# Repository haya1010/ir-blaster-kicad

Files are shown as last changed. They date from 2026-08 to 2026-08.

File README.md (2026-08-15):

# M5 / ESP32 High-Power IR Blaster — Rev A

M5 Atom または ESP32 から家電を操作するための、赤外線送受信ボードです。
既存の `m5-ir-remote-studio` の初期設定に合わせ、送信は GPIO26、受信は GPIO32 を想定しています。

## できること

- 940 nm 高出力IR LEDを3灯同時にパルス駆動
- AO3400A MOSFETでESP32のGPIOを保護
- TSOP38238（38 kHz）でリモコン信号を受信
- 受信部を3.3 Vで動かし、ESP32入力へ安全な電圧で返す
- TX動作確認用の可視LED
- JST-PH 4ピンでM5 Atom／ESP32へ接続
- 52 × 40 mm、M3穴4個

## 接続

| J1 pin | 信号 | M5 Atom / ESP32 |
|---|---|---|
| 1 | IR_TX | GPIO26 |
| 2 | IR_RX | GPIO32 |
| 3 | +5V | 5V |
| 4 | GND | GND |

J1のシルク面表記は左から `TX / RX / 5V / GND` です。Groveケーブルは製品により信号線の割り当てが異なるため、色だけで判断せず導通を確認してください。

## 電気的な目安

IR LED 1灯あたりのピーク電流は、5 V、順方向電圧約1.35 V、33 Ωとして約111 mAです。
3灯合計は送信パルス中に約333 mAとなります。38 kHz変調かつ短いリモコン送信を前提としています。

連続点灯はしないでください。IR LEDにはパルス定格に余裕のある部品（TSAL6200相当）を使い、R3〜R5はパルス負荷に耐える0.5 W品を推奨します。

## KiCadで開く

`m5_ir_blaster.kicad_pro` または `m5_ir_blaster.kicad_pcb` を開いてください。
フットプリントはPCBファイル内に埋め込んであるため、追加ライブラリは不要です。

## JLCPCBで基板だけ注文する

アップロードするファイルは `manufacturing/m5_ir_blaster_revA_gerbers.zip` です。
KiCadプロジェクトZIPではなく、Gerber ZIPの方を使ってください。

推奨する初回設定:

| 項目 | 設定 |
|---|---|
| Base Material | FR-4 |
| Layers | 2 |
| Dimensions | 52 × 40 mm（自動認識を確認） |
| PCB Qty | 5 |
| Thickness | 1.6 mm |
| Copper Weight | 1 oz |
| PCB Color | Green（好みで変更可） |
| Silkscreen | White |
| Surface Finish | LeadFree HASL |
| Via Covering | Tented |
| Remove Order Number | 見た目優先なら Yes |
| PCB Assembly | No（部品は手はんだ） |

アップロード後のGerber Viewerで、外形、M3穴4個、IR LED穴3組、J1の4ピン穴、表面シルクを確認してください。

## 製造前の確認

これは試作Rev Aです。発注前に次を確認してください。

1. 使用するJSTコネクタの実物とピン順
2. 選んだIR LEDの極性と最大パルス電流
3. TSOP38238互換品のピン配列（OUT / GND / VS）
4. KiCadのDRC
5. 実機の5 V供給能力

## データシート確認済みの要点

- MCP1700 SOT-23: 1=GND、2=VOUT、3=VIN
- TSOP38238: 1=OUT、2=GND、3=VS
- TSAL6200: 940 nm、連続100 mA、規定条件でピーク200 mA
- AO3400A: 2.5 Vゲート駆動時のオン抵抗が規定されたロジックレベルMOSFET

メーカー資料:

- https://www.microchip.com/en-us/product/mcp1700
- https://www.vishay.com/docs/82491/tsop382.pdf
- https://www.vishay.com/docs/81010/tsal6200.pdf
- https://www.aosmd.com/products/mosfets/low-voltage-mosfets-12v-30v/ao3400a

## ファームウェア

既存スケッチの設定をそのまま使用できます。

```cpp
static const uint16_t IR_RX_PIN = 32;
static const uint16_t IR_TX_PIN = 26;
```

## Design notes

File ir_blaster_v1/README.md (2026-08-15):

# IR Blaster V1 — ESP32 DevKitC 38-pin shield

写真のユニバーサル基板版を、74.0 mm円形・2層PCBとして再構成したKiCad 9プロジェクトです。12灯のLEDとESP32用1×19ピンソケット2本は、ユーザーの指定により **DNP（未実装）** とし、スルーホール、極性表示、外向き矢印だけを用意しています。

## 確定仕様

- `BOARD_DIAMETER_MM = 74.0`
- 2-layer FR-4、1.6 mm、1 oz
- 推奨色: White solder mask / Black silkscreen
- ESP32 DevKitC V4: 2.54 mmピッチ×19、2列間隔25.40 mm、基板幅27.94 mm
- IR LED: 12個。広角4個（0/90/180/270°）、狭角8個（その間の30°刻み）
- LED/ESP32ソケット: DNP、ユーザー手はんだ
- GPIO25 → 220 Ω → INK021ABS1 gate、10 kΩ pull-down
- 5 V–GND: 1000 µF + 100 nF

## ファイル

- `ir_blaster_v1.kicad_pro/.kicad_sch/.kicad_pcb`: KiCadプロジェクト
- `manufacturing/`: Gerber、Excellon、製造ZIP
- `assembly/`: BOM/CPL候補（LEDとソケットは除外）
- `docs/`: 回路図、基板PDF、組立図
- `preview/`: Top/Bottom/3D PNG
- `BOM.csv`, `BOM_REVIEW.md`, `DESIGN_REVIEW.md`, `JLCPCB_ORDER_GUIDE.md`, `ASSUMPTIONS.md`

## 検証結果

- KiCad ERC: 0 error / 0 warning
- KiCad PCB DRC: 0 DRC violations
- KiCad 9.0.6では、塗り潰し済み+5Vゾーンが自分自身の同一点を指す `1 unconnected pads` 診断を出します。部品パッド間の未配線ではなく、Gerberと銅箔PDFでゾーン連続性を確認しています。

## 発注前に必ず確認

1. 手元のESP32ボードが公式DevKitC V4互換の25.40 mm列間隔・19ピンであること。
2. 使用するメスソケットのピンが1.0 mm完成穴を通ること。
3. LEDは1番穴=A、2番穴=K。全12個を外向き30〜45°程度に手はんだすること。
4. Q1の3.3 V動作はメーカー保証値ではないため、最初は電流制限付き電源で確認すること。
5. JLCPCB注文画面でQ1およびTHT受動部品の実在庫・フットプリントを再確認すること。

## 公式資料

- Espressif DevKitC V4: https://docs.espressif.com/projects/esp-dev-kits/en/latest/esp32/esp32-devkitc/user_guide.html
- DevKitC寸法PDF: https://dl.espressif.com/dl/schematics/esp32_devkitc_v4_dimensions.pdf
- OSI5LA5A33A-B datasheet: https://akizukidenshi.com/goodsaffix/OSI5LA5A33A-B.pdf
- OSI5LA7WA1B datasheet: https://akizukidenshi.com/goodsaffix/OSI5LA7WA1B.pdf
- INK021ABS1 datasheet: https://www.idc-com.co.jp/product/Search/Pdf/en/121/INK021ABS1/0/

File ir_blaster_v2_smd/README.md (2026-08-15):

# IR Blaster V2 SMD

Cost-optimized derivative of `ir_blaster_v1`.

- User hand solder: D1-D12 IR LEDs, J1/J2 ESP32 DevKit sockets, Cbulk 1000 uF
- JLCPCB top-side SMT: R1-R12, RG, RPD, Q1, Cdec
- R1-R12 use 1206 250 mW parts for LED-current resistor power margin
- Q1 changes from the THT INK021ABS1 to the 3.3 V logic-level AO3400A (SOT-23)
- Electrical control remains GPIO25 through 220 ohm gate resistance with 10 kohm pull-down

Manufacturing uploads:

- `manufacturing/ir_blaster_v2_smd_gerbers_jlc.zip`
- `assembly/BOM_JLCPCB.csv`
- `assembly/CPL_JLCPCB.csv`

Do not place an order until the final KiCad zone-fill/connectivity and JLCPCB placement preview have been reviewed.

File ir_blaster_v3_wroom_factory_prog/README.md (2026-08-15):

# IR Blaster V3 — WROOM Factory Programming Interface

This is a separate KiCad revision. It does not overwrite `ir_blaster_v1` or
`ir_blaster_v2_smd`.

## Scope

This revision implements the section-8 programming interface milestone:

- ESP32-WROOM-32E-N16 footprint and UART0 programming nets
- bottom-side six-pad factory pogo interface
- separate 2.54 mm 1x6 prototype header, marked DNP
- pin-1 and per-signal silkscreen labels
- JLCPCB BOM/CPL and fabrication outputs
- safe programming instructions

It is an integration milestone, not yet the complete standalone product. USB-C,
the regulator, IR LED drivers, IR receiver, bulk capacitor, buttons and final
case/3D interference checks still need to be merged from the master specification
before a production order.

## Pinout

| Pin | Net | Board label |
|---:|---|---|
| 1 | +3V3 | 3V3 |
| 2 | GND | GND |
| 3 | ESP32 TXD0 | TX |
| 4 | ESP32 RXD0 | RX |
| 5 | EN | EN |
| 6 | IO0 | IO0 |

The bottom pogo pads use the same order in a straight 1x6 array at 3.81 mm
pitch. Pad diameter is 2.4 mm and pad 1 is rectangular.

## Verification status

- PCB DRC: 0 electrical errors, 0 unconnected pads
- Schematic ERC: 0 violations
- Remaining DRC warnings: embedded custom pogo footprint library entries and
  the intentional WROOM footprint change described below

The official KiCad `ESP32-WROOM-32E` land pattern is used. Its 0.20 mm exposed-
pad thermal-via drills were enlarged to 0.30 mm with 0.70 mm pads to fit the
normal JLCPCB manufacturing capability/cost class. This intentional difference
is why KiCad reports a library mismatch warning for U1.

## Manufacturing files

- `manufacturing/gerbers/`: Gerber and drill files
- `manufacturing/ir_blaster_v3_wroom_factory_prog_gerbers.zip`: PCB upload ZIP
- `assembly/BOM_JLCPCB.csv`: assembled parts only
- `assembly/CPL_JLCPCB.csv`: placement data
- `BOM.csv`: engineering BOM including DNP items

`J_PROG` and all pogo pads are PCB-only/DNP and are excluded from the JLCPCB
production BOM and placement file.

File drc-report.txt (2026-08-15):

** Drc report for m5_ir_blaster.kicad_pcb **
** Created on 2026-07-31T15:13:33+0900 **

** Found 0 DRC violations **

** Found 0 unconnected pads **

** Found 0 Footprint errors **

** End of Report **

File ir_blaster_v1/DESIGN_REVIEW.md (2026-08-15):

# Design review

## 電気計算

前提を `VLED = 1.6 V`、`R = 100 Ω`、`VDS = 0.2 V` とすると、1灯のパルス電流は `(5 - 1.6 - 0.2) / 100 = 32 mA`、12灯合計は約384 mAです。抵抗損失は1本あたり約0.102 Wで、指定の0.25 W品に対して余裕があります。

INK021ABS1はメーカー資料で1=Source、2=Drain、3=Gateです。`RDS(on)` は `VGS=4.5 V, ID=1 A` でtyp 0.2 Ω / max 0.35 Ωですが、3.3 Vでの最大値は保証されません。グラフから0.4 A級のスイッチングは現実的と判断できますが、量産保証には不足します。0.35 Ωを仮定した12灯ON時損失は約52 mW、0.6 Ωでも約88 mWです。V1は動作済み試作との同等性を優先して部品を維持しました。

代替候補を使う場合は、3.3 V以下で`RDS(on)`最大値が規定されたlogic-level MOSFETを選び、ピン配列とフットプリントを別リビジョンで再検証してください。V1の製造ファイルでは勝手に置換していません。

Gateは220 Ωと入力容量typ 660 pFから、単純化した時定数が約145 nsです。38 kHz周期26.3 µsに対して十分短く、GPIOの定常電流はほぼ0です。

1000 µFは短いmarkで5 Vバスの落ち込みを抑えます。384 mAを600 µs補う理想計算では約0.23 V低下します。長いmarkをコンデンサだけで支えるものではありません。

38 kHzでLED駆動デューティ1/3なら、mark中の平均LED電流は約128 mAです。プロトコルのspaceを含む送信全体平均はさらに低下します。ただしESP32のWi‑Fiピークと同時に最大約0.4 Aを追加するため、品質のよい5 V / 1 A以上のUSB電源を推奨します。Espressifの注意どおり、USB・5Vピン・3V3ピンから複数電源を同時供給しないでください。

## LED実装方針

JLCPCBは部品ライブラリ上でwave soldering指定されたTHT部品やmanual insertionを扱えます。一方、通常のTHT注文だけで「LED光軸を外向き30〜45°に揃える」ことを保証する公開標準は確認できません。今回はユーザー指定どおりOption C、すなわちLEDをDNPにして手はんだします。基板にはA/K、カソード帯、外向き矢印を入れています。

## ESP32メカ

公式寸法の25.40 mm列間隔、2.54 mmピッチ、19ピンを採用しました。USB側を基板下方向にし、アンテナ側を上方向に表示しています。円形基板と公式DevKitC外形は一部重なるため、アンテナ直下の中央上部に配線を密集させない配置としています。クローン基板は外形・USB・ボタン位置が異なることがあるため実物照合が必要です。

## Photo prototype vs New PCB

| 項目 | Photo prototype | New PCB V1 |
|---|---|---|
| LED数 | 12 | 12 |
| LED種類 | 青透明8、透明wide 4に見える | narrow 8 / wide 4 |
| LED位置 | 円周方向 | 30°刻みの12方向 |
| LED方向 | 外向きに傾斜 | 穴は垂直、手はんだ時に外向き30〜45° |
| コンデンサ | 中央付近 | 中央付近 |
| MOSFET | 中央付近 | 中央付近、S/D/G表示 |
| ESP32 | 下側に積層 | 25.40 mmソケット2列で下側に積層 |
| USB方向 | 円の外側方向 | `USB ↓` |
| 外径 | 写真から約70 mm級 | 74.0 mm |

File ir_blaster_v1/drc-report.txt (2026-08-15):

** Drc report for ir_blaster_v1.kicad_pcb **
** Created on 2026-08-11T19:46:53+0900 **

** Found 0 DRC violations **

** Found 1 unconnected pads **
[unconnected_items]: アイテム間の接続が見つからない
    ローカル オーバーライド; error
    @(100.0000 mm, 77.5000 mm): ゾーン [+5V] F.Cu 上, 優先度 0
    @(100.0000 mm, 77.5000 mm): ゾーン [+5V] F.Cu 上, 優先度 0

** Found 0 Footprint errors **

** End of Report **

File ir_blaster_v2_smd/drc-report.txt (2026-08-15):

** Drc report for ir_blaster_v2_smd.kicad_pcb **
** Created on 2026-08-11T20:14:26+0900 **

** Found 169 DRC violations **
[via_dangling]: ビアがレイヤーに未接続か、単一のレイヤーにのみ接続
    ローカル オーバーライド; warning
    @(99.0000 mm, 116.9500 mm): ビア [GND] (F.Cu - B.Cu 上)
[via_dangling]: ビアがレイヤーに未接続か、単一のレイヤーにのみ接続
    ローカル オーバーライド; warning
    @(108.0000 mm, 116.9500 mm): ビア [GND] (F.Cu - B.Cu 上)
[via_dangling]: ビアがレイヤーに未接続か、単一のレイヤーにのみ接続
    ローカル オーバーライド; warning
    @(102.9000 mm, 101.0000 mm): ビア [GND] (F.Cu - B.Cu 上)
[lib_footprint_issues]: 現在の構成にはフットプリント ライブラリ 'IR_Blaster' が含まれていません。
    ローカル オーバーライド; warning
    @(100.0000 mm, 67.8000 mm): フットプリント D1
[lib_footprint_mismatch]: フットプリント 'R_1206_3216Metric' が、ライブラリ 'Resistor_SMD' のコピーと一致しません。
    ローカル オーバーライド; warning
    @(100.0000 mm, 78.0000 mm): フットプリント R1
[lib_footprint_issues]: 現在の構成にはフットプリント ライブラリ 'IR_Blaster' が含まれていません。
    ローカル オーバーライド; warning
    @(116.1000 mm, 72.1140 mm): フットプリント D2
[lib_footprint_mismatch]: フットプリント 'R_1206_3216Metric' が、ライブラリ 'Resistor_SMD' のコピーと一致しません。
    ローカル オーバーライド; warning
    @(107.5000 mm, 87.0100 mm): フットプリント R2
[lib_footprint_issues]: 現在の構成にはフットプリント ライブラリ 'IR_Blaster' が含まれていません。
    ローカル オーバーライド; warning
    @(127.8860 mm, 83.9000 mm): フットプリント D3
[lib_footprint_mismatch]: フットプリント 'R_1206_3216Metric' が、ライブラリ 'Resistor_SMD' のコピーと一致しません。
    ローカル オーバーライド; warning
    @(119.0530 mm, 89.0000 mm): フットプリント R3
[lib_footprint_issues]: 現在の構成にはフットプリント ライブラリ 'IR_Blaster' が含まれていません。
    ローカル オーバーライド; warning
    @(132.2000 mm, 100.0000 mm): フットプリント D4
[lib_footprint_mismatch]: フットプリント 'R_1206_3216Metric' が、ライブラリ 'Resistor_SMD' のコピーと一致しません。
    ローカル オーバーライド; warning
    @(122.0000 mm, 100.0000 mm): フットプリント R4
[lib_footprint_issues]: 現在の構成にはフットプリント ライブラリ 'IR_Blaster' が含まれていません。
    ローカル オーバーライド; warning
    @(127.8860 mm, 116.1000 mm): フットプリント D5
[lib_footprint_mismatch]: フットプリント 'R_1206_3216Metric' が、ライブラリ 'Resistor_SMD' のコピーと一致しません。
    ローカル オーバーライド; warning
    @(119.0530 mm, 111.0000 mm): フットプリント R5
[lib_footprint_issues]: 現在の構成にはフットプリント ライブラリ 'IR_Blaster' が含まれていません。
    ローカル オーバーライド; warning
    @(116.1000 mm, 127.8860 mm): フットプリント D6
[lib_footprint_mismatch]: フットプリント 'R_1206_3216Metric' が、ライブラリ 'Resistor_SMD' のコピーと一致しません。
    ローカル オーバーライド; warning
    @(111.0000 mm, 119.0530 mm): フットプリント R6
[lib_footprint_issues]: 現在の構成にはフットプリント ライブラリ 'IR_Blaster' が含まれていません。
    ローカル オーバーライド; warning
    @(100.0000 mm, 132.2000 mm): フットプリント D7
[lib_footprint_mismatch]: フットプリント 'R_1206_3216Metric' が、ライブラリ 'Resistor_SMD' のコピーと一致しません。
    ローカル オーバーライド; warning
    @(100.0000 mm, 122.0000 mm): フットプリント R7
[lib_footprint_issues]: 現在の構成にはフットプリント ライブラリ 'IR_Blaster' が含まれていません。
    ローカル オーバーライド; warning
    @(83.9000 mm, 127.8860 mm): フットプリント D8
[lib_footprint_mismatch]: フットプリント 'R_1206_3216Metric' が、ライブラリ 'Resistor_SMD' のコピーと一致しません。
    ローカル オーバーライド; warning
    @(89.0000 mm, 119.0530 mm): フットプリント R8
[lib_footprint_issues]: 現在の構成にはフットプリント ライブラリ 'IR_Blaster' が含まれていません。
    ローカル オーバーライド; warning
    @(72.1140 mm, 116.1000 mm): フットプリント D9
[lib_footprint_mismatch]: フットプリント 'R_1206_3216Metric' が、ライブラリ 'Resistor_SMD' のコピーと一致しません。
    ローカル オーバーライド; warning
    @(80.9470 mm, 111.0000 mm): フットプリント R9
[lib_footprint_issues]: 現在の構成にはフットプリント ライブラリ 'IR_Blaster' が含まれていません。
    ローカル オーバーライド; warning
    @(67.8000 mm, 100.0000 mm): フットプリント D10
[lib_footprint_mismatch]: フットプリント 'R_1206_3216Metric' が、ライブラリ 'Resistor_SMD' のコピーと一致しません。
    ローカル オーバーライド; warning
    @(78.0000 mm, 100.0000 mm): フットプリント R10
[lib_footprint_issues]: 現在の構成にはフットプリント ライブラリ 'IR_Blaster' が含まれていません。
    ローカル オーバーライド; warning
    @(72.1140 mm, 83.9000 mm): フットプリント D11
[lib_footprint_mismatch]: フットプリント 'R_1206_3216Metric' が、ライブラリ 'Resistor_SMD' のコピーと一致しません。
    ローカル オーバーライド; warning
    @(80.9470 mm, 89.0000 mm): フットプリント R11
[lib_footprint_issues]: 現在の構成にはフットプリント ライブラリ 'IR_Blaster' が含まれていません。
    ローカル オーバーライド; warning
    @(83.9000 mm, 72.1140 mm): フットプリント D12
[lib_footprint_mismatch]: フットプリント 'R_1206_3216Metric' が、ライブラリ 'Resistor_SMD' のコピーと一致しません。
    ローカル オーバーライド; warning
    @(92.5000 mm, 87.0100 mm): フットプリント R12
[lib_footprint_issues]: 現在の構成にはフットプリント ライブラリ 'IR_Blaster' が含まれていません。
    ローカル オーバーライド; warning
    @(87.3000 mm, 72.0000 mm): フットプリント J1
[lib_footprint_issues]: 現在の構成にはフットプリント ライブラリ 'IR_Blaster' が含まれていません。
    ローカル オーバーライド; warning
    @(112.7000 mm, 72.0000 mm): フットプリント J2
[lib_footprint_mismatch]: フットプリント 'SOT-23' が、ライブラリ 'Package_TO_SOT_SMD' のコピーと一致しません。
    ローカル オーバーライド; warning
    @(100.0000 mm, 116.0000 mm): フットプリント Q1
[lib_footprint_mismatch]: フットプリント 'R_0603_1608Metric' が、ライブラリ 'Resistor_SMD' のコピーと一致しません。
    ローカル オーバーライド; warning
    @(104.0000 mm, 109.0000 mm): フットプリント RG
[lib_footprint_mismatch]: フットプリント 'R_0603_1608Metric' が、ライブラリ 'Resistor_SMD' のコピーと一致しません。
    ローカル オーバーライド; warning
    @(108.0000 mm, 116.0000 mm): フットプリント RPD
[lib_footprint_issues]: 現在の構成にはフットプリント ライブラリ 'IR_Blaster' が含まれていません。
    ローカル オーバーライド; warning
    @(94.0000 mm, 106.0000 mm): フットプリント Cbulk
[lib_footprint_mismatch]: フットプリント 'C_0603_1608Metric' が、ライブラリ 'Capacitor_SMD' のコピーと一致しません。
    ローカル オーバーライド; warning
    @(102.0000 mm, 101.0000 mm): フットプリント Cdec
[lib_footprint_issues]: 現在の構成にはフットプリント ライブラリ 'IR_Blaster' が含まれていません。
    ローカル オーバーライド; warning
    @(94.0000 mm, 95.0000 mm): フットプリント TP1
[lib_footprint_issues]: 現在の構成にはフットプリント ライブラリ 'IR_Blaster' が含まれていません。
    ローカル オーバーライド; warning
    @(106.0000 mm, 95.0000 mm): フットプリント TP2
[lib_footprint_issues]: 現在の構成にはフットプリント ライブラリ 'IR_Blaster' が含まれていません。
    ローカル オーバーライド; warning
    @(96.0000 mm, 102.0000 mm): フットプリント TP3
[lib_footprint_issues]: 現在の構成にはフットプリント ライブラリ 'IR_Blaster' が含まれていません。
    ローカル オーバーライド; warning
    @(103.0000 mm, 120.0000 mm): フットプリント TP4
[text_height]: 文字の高さが許容範囲外 (基板の設定のシルク印刷のテキスト高の制約 最小高さ 0.8000 mm; 現状 0.7500 mm)
    ルール: 基板の設定のシルク印刷のテキスト高の制約; warning
    @(100.0000 mm, 94.5000 mm): 基板上のテキスト '12 x 940nm / GPIO25' ( f.silkscreen 上)
[text_height]: 文字の高さが許容範囲外 (基板の設定のシルク印刷のテキスト高の制約 最小高さ 0.8000 mm; 現状 0.7000 mm)
    ルール: 基板の設定のシルク印刷のテキスト高の制約; warning
    @(100.0000 mm, 64.2000 mm): 基板上のテキスト 'ESP32 ANTENNA EDGE ↑' ( f.silkscreen 上)
[text_height]: 文字の高さが許容範囲外 (基板の設定のシルク印刷のテキスト高の制約 最小高さ 0.8000 mm; 現状 0.6200 mm)
    ルール: 基板の設定のシルク印刷のテキスト高の制約; warning
    @(100.0000 mm, 129.8000 mm): 基板上のテキスト 'LED + SOCKETS: DNP / USER SOLDER' ( f.silkscreen 上)
[text_height]: 文字の高さが許容範囲外 (基板の設定のシルク印刷のテキスト高の制約 最小高さ 0.8000 mm; 現状 0.5800 mm)
    ルール: 基板の設定のシルク印刷のテキスト高の制約; warning
    @(100.0000 mm, 127.8000 mm): 基板上のテキスト 'SMD PASSIVES + AO3400A PCBA' ( f.silkscreen 上)
[text_height]: 文字の高さが許容範囲外 (基板の設定のシルク印刷のテキスト高の制約 最小高さ 0.8000 mm; 現状 0.7000 mm)
    ルール: 基板の設定のシルク印刷のテキスト高の制約; warning
    @(84.5000 mm, 118.0000 mm): 基板上のテキスト '5V' ( f.silkscreen 上)
[text_height]: 文字の高さが許容範囲外 (基板の設定のシルク印刷のテキスト高の制約 最小高さ 0.8000 mm; 現状 0.7000 mm)
    ルール: 基板の設定のシルク印刷のテキスト高の制約; warning
    @(84.0000 mm, 105.0000 mm): 基板上のテキスト 'GND' ( f.silkscreen 上)
[text_height]: 文字の高さが許容範囲外 (基板の設定のシルク印刷のテキスト高の制約 最小高さ 0.8000 mm; 現状 0.6500 mm)
    ルール: 基板の設定のシルク印刷のテキスト高の制約; warning
    @(83.0000 mm, 92.3000 mm): 基板上のテキスト 'GPIO25' ( f.silkscreen 上)
[text_height]: 文字の高さが許容範囲外 (基板の設定のシルク印刷のテキスト高の制約 最小高さ 0.8000 mm; 現状 0.7000 mm)
    ルール: 基板の設定のシルク印刷のテキスト高の制約; warning
    @(102.8000 mm, 69.0700 mm): D1 のフットプリント テキスト ( A )
[text_height]: 文字の高さが許容範囲外 (基板の設定のシルク印刷のテキスト高の制約 最小高さ 0.8000 mm; 現状 0.7000 mm)
    ルール: 基板の設定のシルク印刷のテキスト高の制約; warning
    @(102.8000 mm, 66.5300 mm): D1 のフットプリント テキスト ( K )
[text_height]: 文字の高さが許容範囲外 (基板の設定のシルク印刷のテキスト高の制約 最小高さ 0.8000 mm; 現状 0.6500 mm)
    ルール: 基板の設定のシルク印刷のテキスト高の制約; warning
    @(95.2000 mm, 67.8000 mm): D1 のフットプリント テキスト ( OUT → )
[text_height]: 文字の高さが許容範囲外 (基板の設定のシルク印刷のテキスト高の制約 最小高さ 0.8000 mm; 現状 0.6500 mm)
    ルール: 基板の設定のシルク印刷のテキスト高の制約; warning
    @(98.0000 mm, 78.0000 mm): R1のリファレンスフィールド
[text_height]: 文字の高さが許容範囲外 (基板の設定のシルク印刷のテキスト高の制約 最小高さ 0.8000 mm; 現状 0.7000 mm)
    ルール: 基板の設定のシルク印刷のテキスト高の制約; warning
    @(117.8899 mm, 74.6139 mm): D2 のフットプリント テキスト ( A )
[text_height]: 文字の高さが許容範囲外 (基板の設定のシルク印刷のテキスト高の制約 最小高さ 0.8000 mm; 現状 0.7000 mm)
    ルール: 基板の設定のシルク印刷のテキスト高の制約; warning
    @(119.1599 mm, 72.4141 mm): D2 のフットプリント テキスト ( K )
[text_height]: 文字の高さが許容範囲外 (基板の設定のシルク印刷のテキスト高の制約 最小高さ 0.8000 mm; 現状 0.6500 mm)
    ルール: 基板の設定のシルク印刷のテキスト高の制約; warning
    @(111.9431 mm, 69.7140 mm): D2 のフットプリント テキスト ( OUT → )
[text_height]: 文字の高さが許容範囲外 (基板の設定のシルク印刷のテキスト高の制約 最小高さ 0.8000 mm; 現状 0.6500 mm)
    ルール: 基板の設定のシルク印刷のテキスト高の制約; warning
    @(105.7679 mm, 86.0100 mm): R2のリファレンスフィールド
[text_height]: 文字の高さが許容範囲外 (基板の設定のシルク印刷のテキスト高の制約 最小高さ 0.8000 mm; 現状 0.7000 mm)
    ルール: 基板の設定のシルク印刷のテキスト高の制約; warning
    @(128.1861 mm, 86.9599 mm): D3 のフットプリント テキスト ( A )
[text_height]: 文字の高さが許容範囲外 (基板の設定のシルク印刷のテキスト高の制約 最小高さ 0.8000 mm; 現状 0.7000 mm)
    ルール: 基板の設定のシルク印刷のテキスト高の制約; warning
    @(130.3859 mm, 85.6899 mm): D3 のフットプリント テキスト ( K )
[text_height]: 文字の高さが許容範囲外 (基板の設定のシルク印刷のテキスト高の制約 最小高さ 0.8000 mm; 現状 0.6500 mm)
    ルール: 基板の設定のシルク印刷のテキスト高の制約; warning
    @(125.4860 mm, 79.7431 mm): D3 のフットプリント テキスト ( OUT → )
[text_height]: 文字の高さが許容範囲外 (基板の設定のシルク印刷のテキスト高の制約 最小高さ 0.8000 mm; 現状 0.6500 mm)
    ルール: 基板の設定のシルク印刷のテキスト高の制約; warning
    @(118.0530 mm, 87.2679 mm): R3のリファレンスフィールド
[text_height]: 文字の高さが許容範囲外 (基板の設定のシルク印刷のテキスト高の制約 最小高さ 0.8000 mm; 現状 0.7000 mm)
    ルール: 基板の設定のシルク印刷のテキスト高の制約; warning
    @(130.9300 mm, 102.8000 mm): D4 のフットプリント テキスト ( A )
[text_height]: 文字の高さが許容範囲外 (基板の設定のシルク印刷のテキスト高の制約 最小高さ 0.8000 mm; 現状 0.7000 mm)
    ルール: 基板の設定のシルク印刷のテキスト高の制約; warning
    @(133.4700 mm, 102.8000 mm): D4 のフットプリント テキスト ( K )
[text_height]: 文字の高さが許容範囲外 (基板の設定のシルク印刷のテキスト高の制約 最小高さ 0.8000 mm; 現状 0.6500 mm)
    ルール: 基板の設定のシルク印刷のテキスト高の制約; warning
    @(132.2000 mm, 95.2000 mm): D4 のフットプリント テキスト ( OUT → )
[text_height]: 文字の高さが許容範囲外 (基板の設定のシルク印刷のテキスト高の制約 最小高さ 0.8000 mm; 現状 0.6500 mm)
    ルール: 基板の設定のシルク印刷のテキスト高の制約; warning
    @(122.0000 mm, 98.0000 mm): R4のリファレンスフィールド
[text_height]: 文字の高さが許容範囲外 (基板の設定のシルク印刷のテキスト高の制約 最小高さ 0.8000 mm; 現状 0.7000 mm)
    ルール: 基板の設定のシルク印刷のテキスト高の制約; warning
    @(125.3861 mm, 117.8899 mm): D5 のフットプリント テキスト ( A )
[text_height]: 文字の高さが許容範囲外 (基板の設定のシルク印刷のテキスト高の制約 最小高さ 0.8000 mm; 現状 0.7000 mm)
    ルール: 基板の設定のシルク印刷のテキスト高の制約; warning
    @(127.5859 mm, 119.1599 mm): D5 のフットプリント テキスト ( K )
[text_height]: 文字の高さが許容範囲外 (基板の設定のシルク印刷のテキスト高の制約 最小高さ 0.8000 mm; 現状 0.6500 mm)
    ルール: 基板の設定のシルク印刷のテキスト高の制約; warning
    @(130.2860 mm, 111.9431 mm): D5 のフットプリント テキスト ( OUT → )
[text_height]: 文字の高さが許容範囲外 (基板の設定のシルク印刷のテキスト高の制約 最小高さ 0.8000 mm; 現状 0.6500 mm)
    ルール: 基板の設定のシルク印刷のテキスト高の制約; warning
    @(120.0530 mm, 109.2679 mm): R5のリファレンスフィールド
[text_height]: 文字の高さが許容範囲外 (基板の設定のシルク印刷のテキスト高の制約 最小高さ 0.8000 mm; 現状 0.7000 mm)
    ルール: 基板の設定のシルク印刷のテキスト高の制約; warning
    @(113.0401 mm, 128.1861 mm): D6 のフットプリント テキスト ( A )
[text_height]: 文字の高さが許容範囲外 (基板の設定のシルク印刷のテキスト高の制約 最小高さ 0.8000 mm; 現状 0.7000 mm)
    ルール: 基板の設定のシルク印刷のテキスト高の制約; warning
    @(114.3101 mm, 130.3859 mm): D6 のフットプリント テキスト ( K )
[text_height]: 文字の高さが許容範囲外 (基板の設定のシルク印刷のテキスト高の制約 最小高さ 0.8000 mm; 現状 0.6500 mm)
    ルール: 基板の設定のシルク印刷のテキスト高の制約; warning
    @(120.2569 mm, 125.4860 mm): D6 のフットプリント テキスト ( OUT → )
[text_height]: 文字の高さが許容範囲外 (基板の設定のシルク印刷のテキスト高の制約 最小高さ 0.8000 mm; 現状 0.6500 mm)
    ルール: 基板の設定のシルク印刷のテキスト高の制約; warning
    @(112.7321 mm, 118.0530 mm): R6のリファレンスフィールド
[text_height]: 文字の高さが許容範囲外 (基板の設定のシルク印刷のテキスト高の制約 最小高さ 0.8000 mm; 現状 0.7000 mm)
    ルール: 基板の設定のシルク印刷のテキスト高の制約; warning
    @(97.2000 mm, 130.9300 mm): D7 のフットプリント テキスト ( A )
[text_height]: 文字の高さが許容範囲外 (基板の設定のシルク印刷のテキスト高の制約 最小高さ 0.8000 mm; 現状 0.7000 mm)
    ルール: 基板の設定のシルク印刷のテキスト高の制約; warning
    @(97.2000 mm, 133.4700 mm): D7 のフットプリント テキスト ( K )
[text_height]: 文字の高さが許容範囲外 (基板の設定のシルク印刷のテキスト高の制約 最小高さ 0.8000 mm; 現状 0.6500 mm)
    ルール: 基板の設定のシルク印刷のテキスト高の制約; warning
    @(104.8000 mm, 132.2000 mm): D7 のフットプリント テキスト ( OUT → )
[text_height]: 文字の高さが許容範囲外 (基板の設定のシルク印刷のテキスト高の制約 最小高さ 0.8000 mm; 現状 0.6500 mm)
    ルール: 基板の設定のシルク印刷のテキスト高の制約; warning
    @(102.0000 mm, 122.0000 mm): R7のリファレンスフィールド
[text_height]: 文字の高さが許容範囲外 (基板の設定のシルク印刷のテキスト高の制約 最小高さ 0.8000 mm; 現状 0.7000 mm)
    ルール: 基板の設定のシルク印刷のテキスト高の制約; warning
    @(82.1101 mm, 125.3861 mm): D8 のフットプリント テキスト ( A )
[text_height]: 文字の高さが許容範囲外 (基板の設定のシルク印刷のテキスト高の制約 最小高さ 0.8000 mm; 現状 0.7000 mm)
    ルール: 基板の設定のシルク印刷のテキスト高の制約; warning
    @(80.8401 mm, 127.5859 mm): D8 のフットプリント テキスト ( K )
[text_height]: 文字の高さが許容範囲外 (基板の設定のシルク印刷のテキスト高の制約 最小高さ 0.8000 mm; 現状 0.6500 mm)
    ルール: 基板の設定のシルク印刷のテキスト高の制約; warning
    @(88.0569 mm, 130.2860 mm): D8 のフットプリント テキスト ( OUT → )
[text_height]: 文字の高さが許容範囲外 (基板の設定のシルク印刷のテキスト高の制約 最小高さ 0.8000 mm; 現状 0.6500 mm)
    ルール: 基板の設定のシルク印刷のテキスト高の制約; warning
    @(90.7321 mm, 120.0530 mm): R8のリファレンスフィールド
[text_height]: 文字の高さが許容範囲外 (基板の設定のシルク印刷のテキスト高の制約 最小高さ 0.8000 mm; 現状 0.7000 mm)
    ルール: 基板の設定のシルク印刷のテキスト高の制約; warning
    @(71.8139 mm, 113.0401 mm): D9 のフットプリント テキスト ( A )
[text_height]: 文字の高さが許容範囲外 (基板の設定のシルク印刷のテキスト高の制約 最小高さ 0.8000 mm; 現状 0.7000 mm)
    ルール: 基板の設定のシルク印刷のテキスト高の制約; warning
    @(69.6141 mm, 114.3101 mm): D9 のフットプリント テキスト ( K )
[text_height]: 文字の高さが許容範囲外 (基板の設定のシルク印刷のテキスト高の制約 最小高さ 0.8000 mm; 現状 0.6500 mm)
    ルール: 基板の設定のシルク印刷のテキスト高の制約; warning
    @(74.5140 mm, 120.2569 mm): D9 のフットプリント テキスト ( OUT → )
[text_height]: 文字の高さが許容範囲外 (基板の設定のシルク印刷のテキスト高の制約 最小高さ 0.8000 mm; 現状 0.6500 mm)
    ルール: 基板の設定のシルク印刷のテキスト高の制約; warning
    @(81.9470 mm, 112.7321 mm): R9のリファレンスフィールド
[text_height]: 文字の高さが許容範囲外 (基板の設定のシルク印刷のテキスト高の制約 最小高さ 0.8000 mm; 現状 0.7000 mm)
    ルール: 基板の設定のシルク印刷のテキスト高の制約; warning
    @(69.0700 mm, 97.2000 mm): D10 のフットプリント テキスト ( A )
[text_height]: 文字の高さが許容範囲外 (基板の設定のシルク印刷のテキスト高の制約 最小高さ 0.8000 mm; 現状 0.7000 mm)
    ルール: 基板の設定のシルク印刷のテキスト高の制約; warning
    @(66.5300 mm, 97.2000 mm): D10 のフットプリント テキスト ( K )
[text_height]: 文字の高さが許容範囲外 (基板の設定のシルク印刷のテキスト高の制約 最小高さ 0.8000 mm; 現状 0.6500 mm)
    ルール: 基板の設定のシルク印刷のテキスト高の制約; warning
    @(67.8000 mm, 104.8000 mm): D10 のフットプリント テキスト ( OUT → )
[text_height]: 文字の高さが許容範囲外 (基板の設定のシルク印刷のテキスト高の制約 最小高さ 0.8000 mm; 現状 0.6500 mm)
    ルール: 基板の設定のシルク印刷のテキスト高の制約; warning
    @(78.0000 mm, 102.0000 mm): R10のリファレンスフィールド
[text_height]: 文字の高さが許容範囲外 (基板の設定のシルク印刷のテキスト高の制約 最小高さ 0.8000 mm; 現状 0.7000 mm)
    ルール: 基板の設定のシルク印刷のテキスト高の制約; warning
    @(74.6139 mm, 82.1101 mm): D11 のフットプリント テキスト ( A )
[text_height]: 文字の高さが許容範囲外 (基板の設定のシルク印刷のテキスト高の制約 最小高さ 0.8000 mm; 現状 0.7000 mm)
    ルール: 基板の設定のシルク印刷のテキスト高の制約; warning
    @(72.4141 mm, 80.8401 mm): D11 のフットプリント テキスト ( K )
[text_height]: 文字の高さが許容範囲外 (基板の設定のシルク印刷のテキスト高の制約 最小高さ 0.8000 mm; 現状 0.6500 mm)
    ルール: 基板の設定のシルク印刷のテキスト高の制約; warning
    @(69.7140 mm, 88.0569 mm): D11 のフットプリント テキスト ( OUT → )
[text_height]: 文字の高さが許容範囲外 (基板の設定のシルク印刷のテキスト高の制約 最小高さ 0.8000 mm; 現状 0.6500 mm)
    ルール: 基板の設定のシルク印刷のテキスト高の制約; warning
    @(79.9470 mm, 90.7321 mm): R11のリファレンスフィールド
[text_height]: 文字の高さが許容範囲外 (基板の設定のシルク印刷のテキスト高の制約 最小高さ 0.8000 mm; 現状 0.7000 mm)
    ルール: 基板の設定のシルク印刷のテキスト高の制約; warning
    @(86.9599 mm, 71.8139 mm): D12 のフットプリント テキスト ( A )
[text_height]: 文字の高さが許容範囲外 (基板の設定のシルク印刷のテキスト高の制約 最小高さ 0.8000 mm; 現状 0.7000 mm)
    ルール: 基板の設定のシルク印刷のテキスト高の制約; warning
    @(85.6899 mm, 69.6141 mm): D12 のフットプリント テキスト ( K )
[text_height]: 文字の高さが許容範囲外 (基板の設定のシルク印刷のテキスト高の制約 最小高さ 0.8000 mm; 現状 0.6500 mm)
    ルール: 基板の設定のシルク印刷のテキスト高の制約; warning
    @(79.7431 mm, 74.5140 mm): D12 のフットプリント テキスト ( OUT → )
[text_height]: 文字の高さが許容範囲外 (基板の設定のシルク印刷のテキスト高の制約 最小高さ 0.8000 mm; 現状 0.6500 mm)
    ルール: 基板の設定のシルク印刷のテキスト高の制約; warning
    @(90.7679 mm, 88.0100 mm): R12のリファレンスフィールド
[text_height]: 文字の高さが許容範囲外 (基板の設定のシルク印刷のテキスト高の制約 最小高さ 0.8000 mm; 現状 0.6500 mm)
    ルール: 基板の設定のシルク印刷のテキスト高の制約; warning
    @(105.3000 mm, 109.0000 mm): RGのリファレンスフィールド
[text_height]: 文字の高さが許容範囲外 (基板の設定のシルク印刷のテキスト高の制約 最小高さ 0.8000 mm; 現状 0.6500 mm)
    ルール: 基板の設定のシルク印刷のテキスト高の制約; warning
    @(109.3000 mm, 116.0000 mm): RPDのリファレンスフィールド
[text_height]: 文字の高さが許容範囲外 (基板の設定のシルク印刷のテキスト高の制約 最小高さ 0.8000 mm; 現状 0.6500 mm)
    ルール: 基板の設定のシルク印刷のテキスト高の制約; warning
    @(102.0000 mm, 99.5000 mm): Cdecのリファレンスフィールド
[text_height]: 文字の高さが許容範囲外 (基板の設定のシルク印刷のテキスト高の制約 最小高さ 0.8000 mm; 現状 0.6500 mm)
    ルール: 基板の設定のシルク印刷のテキスト高の制約; warning
    @(94.0000 mm, 93.0000 mm): TP1のリファレンスフィールド
[text_height]: 文字の高さが許容範囲外 (基板の設定のシルク印刷のテキスト高の制約 最小高さ 0.8000 mm; 現状 0.6500 mm)
    ルール: 基板の設定のシルク印刷のテキスト高の制約; warning
    @(94.0000 mm, 97.0000 mm): TP1の値フィールド ( 5V )
[text_height]: 文字の高さが許容範囲外 (基板の設定のシルク印刷のテキスト高の制約 最小高さ 0.8000 mm; 現状 0.6500 mm)
    ルール: 基板の設定のシルク印刷のテキスト高の制約; warning
    @(106.0000 mm, 93.0000 mm): TP2のリファレンスフィールド
[text_height]: 文字の高さが許容範囲外 (基板の設定のシルク印刷のテキスト高の制約 最小高さ 0.8000 mm; 現状 0.6500 mm)
    ルール: 基板の設定のシルク印刷のテキスト高の制約; warning
    @(106.0000 mm, 97.0000 mm): TP2の値フィールド ( GND )
[text_height]: 文字の高さが許容範囲外 (基板の設定のシルク印刷のテキスト高の制約 最小高さ 0.8000 mm; 現状 0.6500 mm)
    ルール: 基板の設定のシルク印刷のテキスト高の制約; warning
    @(96.0000 mm, 100.0000 mm): TP3のリファレンスフィールド
[text_height]: 文字の高さが許容範囲外 (基板の設定のシルク印刷のテキスト高の制約 最小高さ 0.8000 mm; 現状 0.6500 mm)
    ルール: 基板の設定のシルク印刷のテキスト高の制約; warning
    @(96.0000 mm, 104.0000 mm): TP3の値フィールド ( IR_TX )
[text_height]: 文字の高さが許容範囲外 (基板の設定のシルク印刷のテキスト高の制約 最小高さ 0.8000 mm; 現状 0.6500 mm)
    ルール: 基板の設定のシルク印刷のテキスト高の制約; warning
    @(103.0000 mm, 118.0000 mm): TP4のリファレンスフィールド
[text_height]: 文字の高さが許容範囲外 (基板の設定のシルク印刷のテキスト高の制約 最小高さ 0.8000 mm; 現状 0.6500 mm)
    ルール: 基板の設定のシルク印刷のテキスト高の制約; warning
    @(103.0000 mm, 122.0000 mm): TP4の値フィールド ( DRAIN )
[silk_over_copper]: ハンダマスクでシルクスクリーンが切り取られている
    ローカル オーバーライド; warning
    @(100.0000 mm, 94.5000 mm): 基板上のテキスト '12 x 940nm / GPIO25' ( f.silkscreen 上)
[silk_over_copper]: ハンダマスクでシルクスクリーンが切り取られている
    ローカル オーバーライド; warning
    @(100.0000 mm, 133.5000 mm): 基板上のテキスト 'USB ↓' ( f.silkscreen 上)
[silk_over_copper]: ハンダマスクでシルクスクリーンが切り取られている
    ローカル オーバーライド; warning
    @(100.0000 mm, 129.8000 mm): 基板上のテキスト 'LED + SOCKETS: DNP / USER SOLDER' ( f.silkscreen 上)
[silk_over_copper]: ハンダマスクでシルクスクリーンが切り取られている
    ローカル オーバーライド; warning
    @(97.9000 mm, 66.0000 mm): セグメント of D1 、f.silkscreen 上
[silk_over_copper]: ハンダマスクでシルクスクリーンが切り取られている
    ローカル オーバーライド; warning
    @(99.1000 mm, 79.6000 mm): 矩形 of R1 、f.silkscreen 上
[silk_over_copper]: ハンダマスクでシルクスクリーンが切り取られている
    ローカル オーバーライド; warning
    @(116.1000 mm, 72.1140 mm): 円 of D2 、f.silkscreen 上
[silk_over_copper]: ハンダマスクでシルクスクリーンが切り取られている
    ローカル オーバーライド; warning
    @(115.1813 mm, 69.5052 mm): セグメント of D2 、f.silkscreen 上
[silk_over_copper]: ハンダマスクでシルクスクリーンが切り取られている
    ローカル オーバーライド; warning
    @(105.9206 mm, 87.9456 mm): ポリゴン of R2 、f.silkscreen 上
[silk_over_copper]: ハンダマスクでシルクスクリーンが切り取られている
    ローカル オーバーライド; warning
    @(127.8860 mm, 83.9000 mm): 円 of D3 、f.silkscreen 上
[silk_over_copper]: ハンダマスクでシルクスクリーンが切り取られている
    ローカル オーバーライド; warning
    @(128.3948 mm, 81.1813 mm): セグメント of D3 、f.silkscreen 上
[silk_over_copper]: ハンダマスクでシルクスクリーンが切り取られている
    ローカル オーバーライド; warning
    @(117.2174 mm, 89.0206 mm): ポリゴン of R3 、f.silkscreen 上
[silk_over_copper]: ハンダマスクでシルクスクリーンが切り取られている
    ローカル オーバーライド; warning
    @(134.0000 mm, 97.9000 mm): セグメント of D4 、f.silkscreen 上
[silk_over_copper]: ハンダマスクでシルクスクリーンが切り取られている
    ローカル オーバーライド; warning
    @(120.4000 mm, 99.1000 mm): 矩形 of R4 、f.silkscreen 上
[silk_over_copper]: ハンダマスクでシルクスクリーンが切り取られている
    ローカル オーバーライド; warning
    @(127.8860 mm, 116.1000 mm): 円 of D5 、f.silkscreen 上
[silk_over_copper]: ハンダマスクでシルクスクリーンが切り取られている
    ローカル オーバーライド; warning
    @(130.4948 mm, 115.1813 mm): セグメント of D5 、f.silkscreen 上
[silk_over_copper]: ハンダマスクでシルクスクリーンが切り取られている
    ローカル オーバーライド; warning
    @(118.1174 mm, 109.4206 mm): ポリゴン of R5 、f.silkscreen 上
[silk_over_copper]: ハンダマスクでシルクスクリーンが切り取られている
    ローカル オーバーライド; warning
    @(116.1000 mm, 127.8860 mm): 円 of D6 、f.silkscreen 上
[silk_over_copper]: ハンダマスクでシルクスクリーンが切り取られている
    ローカル オーバーライド; warning
    @(118.8187 mm, 128.3948 mm): セグメント of D6 、f.silkscreen 上
[silk_over_copper]: ハンダマスクでシルクスクリーンが切り取られている
    ローカル オーバーライド; warning
    @(112.7321 mm, 118.0530 mm): R6のリファレンスフィールド
[silk_over_copper]: ハンダマスクでシルクスクリーンが切り取られている
    ローカル オーバーライド; warning
    @(110.9794 mm, 117.2174 mm): ポリゴン of R6 、f.silkscreen 上
[silk_over_copper]: ハンダマスクでシルクスクリーンが切り取られている
    ローカル オーバーライド; warning
    @(102.1000 mm, 134.0000 mm): セグメント of D7 、f.silkscreen 上
[silk_over_copper]: ハンダマスクでシルクスクリーンが切り取られている
    ローカル オーバーライド; warning
    @(100.9000 mm, 120.4000 mm): 矩形 of R7 、f.silkscreen 上
[silk_over_copper]: ハンダマスクでシルクスクリーンが切り取られている
    ローカル オーバーライド; warning
    @(83.9000 mm, 127.8860 mm): 円 of D8 、f.silkscreen 上
[silk_over_copper]: ハンダマスクでシルクスクリーンが切り取られている
    ローカル オーバーライド; warning
    @(84.8187 mm, 130.4948 mm): セグメント of D8 、f.silkscreen 上
[silk_over_copper]: ハンダマスクでシルクスクリーンが切り取られている
    ローカル オーバーライド; warning
    @(90.5794 mm, 118.1174 mm): ポリゴン of R8 、f.silkscreen 上
[silk_over_copper]: ハンダマスクでシルクスクリーンが切り取られている
    ローカル オーバーライド; warning
    @(72.1140 mm, 116.1000 mm): 円 of D9 、f.silkscreen 上
[silk_over_copper]: ハンダマスクでシルクスクリーンが切り取られている
    ローカル オーバーライド; warning
    @(71.6052 mm, 118.8187 mm): セグメント of D9 、f.silkscreen 上
[silk_over_copper]: ハンダマスクでシルクスクリーンが切り取られている
    ローカル オーバーライド; warning
    @(82.7826 mm, 110.9794 mm): ポリゴン of R9 、f.silkscreen 上
[silk_over_copper]: ハンダマスクでシルクスクリーンが切り取られている
    ローカル オーバーライド; warning
    @(66.0000 mm, 102.1000 mm): セグメント of D10 、f.silkscreen 上
[silk_over_copper]: ハンダマスクでシルクスクリーンが切り取られている
    ローカル オーバーライド; warning
    @(79.6000 mm, 100.9000 mm): 矩形 of R10 、f.silkscreen 上
[silk_over_copper]: ハンダマスクでシルクスクリーンが切り取られている
    ローカル オーバーライド; warning
    @(72.1140 mm, 83.9000 mm): 円 of D11 、f.silkscreen 上
[silk_over_copper]: ハンダマスクでシルクスクリーンが切り取られている
    ローカル オーバーライド; warning
    @(69.5052 mm, 84.8187 mm): セグメント of D11 、f.silkscreen 上
[silk_over_copper]: ハンダマスクでシルクスクリーンが切り取られている
    ローカル オーバーライド; warning
    @(81.8826 mm, 90.5794 mm): ポリゴン of R11 、f.silkscreen 上
[silk_over_copper]: ハンダマスクでシルクスクリーンが切り取られている
    ローカル オーバーライド; warning
    @(83.9000 mm, 72.1140 mm): 円 of D12 、f.silkscreen 上
[silk_over_copper]: ハンダマスクでシルクスクリーンが切り取られている
    ローカル オーバーライド; warning
    @(81.1813 mm, 71.6052 mm): セグメント of D12 、f.silkscreen 上
[silk_over_copper]: ハンダマスクでシルクスクリーンが切り取られている
    ローカル オーバーライド; warning
    @(86.9599 mm, 71.8139 mm): D12 のフットプリント テキスト ( A )
[silk_over_copper]: ハンダマスクでシルクスクリーンが切り取られている
    ローカル オーバーライド; warning
    @(92.5206 mm, 88.8456 mm): ポリゴン of R12 、f.silkscreen 上
[silk_over_copper]: ハンダマスクでシルクスクリーンが切り取られている
    ローカル オーバーライド; warning
    @(85.7000 mm, 70.4000 mm): 矩形 of J1 、b.silkscreen 上
[silk_over_copper]: ハンダマスクでシルクスクリーンが切り取られている
    ローカル オーバーライド; warning
    @(111.1000 mm, 70.4000 mm): 矩形 of J2 、b.silkscreen 上
[silk_over_copper]: ハンダマスクでシルクスクリーンが切り取られている
    ローカル オーバーライド; warning
    @(98.4000 mm, 114.5000 mm): 矩形 of Q1 、f.silkscreen 上
[silk_over_copper]: ハンダマスクでシルクスクリーンが切り取られている
    ローカル オーバーライド; warning
    @(104.4500 mm, 108.2000 mm): 矩形 of RG 、f.silkscreen 上
[silk_over_copper]: ハンダマスクでシルクスクリーンが切り取られている
    ローカル オーバーライド; warning
    @(108.4500 mm, 115.2000 mm): 矩形 of RPD 、f.silkscreen 上
[silk_over_copper]: ハンダマスクでシルクスクリーンが切り取られている
    ローカル オーバーライド; warning
    @(94.0000 mm, 103.0000 mm): Cbulkのリファレンスフィールド
[silk_over_copper]: ハンダマスクでシルクスクリーンが切り取られている
    ローカル オーバーライド; warning
    @(94.0000 mm, 106.0000 mm): 円 of Cbulk 、f.silkscreen 上
[silk_overlap]: シルクスクリーンのオーバーラップ
    ルール: 基板の設定のシルクスクリーンの制約; warning
    @(100.0000 mm, 133.5000 mm): 基板上のテキスト 'USB ↓' ( f.silkscreen 上)
    @(97.2000 mm, 133.4700 mm): D7 のフットプリント テキスト ( K )
[silk_overlap]: シルクスクリーンのオーバーラップ
    ルール: 基板の設定のシルクスクリーンの制約; warning
    @(102.1000 mm, 134.0000 mm): セグメント of D7 、f.silkscreen 上
    @(100.0000 mm, 133.5000 mm): 基板上のテキスト 'USB ↓' ( f.silkscreen 上)
[silk_overlap]: シルクスクリーンのオーバーラップ
    ルール: 基板の設定のシルクスクリーンの制約; warning
    @(100.0000 mm, 133.5000 mm): 基板上のテキスト 'USB ↓' ( f.silkscreen 上)
    @(101.3500 mm, 129.7000 mm): 矩形 of D7 、f.silkscreen 上
[silk_overlap]: シルクスクリーンのオーバーラップ
    ルール: 基板の設定のシルクスクリーンの制約; warning
    @(101.3500 mm, 129.7000 mm): 矩形 of D7 、f.silkscreen 上
    @(100.0000 mm, 129.8000 mm): 基板上のテキスト 'LED + SOCKETS: DNP / USER SOLDER' ( f.silkscreen 上)
[silk_overlap]: シルクスクリーンのオーバーラップ
    ルール: 基板の設定のシルクスクリーンの制約; warning
    @(103.0000 mm, 122.0000 mm): TP4の値フィールド ( DRAIN )
    @(102.0000 mm, 122.0000 mm): R7のリファレンスフィールド
[silk_overlap]: シルクスクリーンのオーバーラップ
    ルール: 基板の設定のシルクスクリーンの制約; warning
    @(88.0569 mm, 130.2860 mm): D8 のフットプリント テキスト ( OUT → )
    @(87.1043 mm, 129.7360 mm): D8のリファレンスフィールド
[silk_overlap]: シルクスクリーンのオーバーラップ
    ルール: 基板の設定のシルクスクリーンの制約; warning
    @(80.8401 mm, 127.5859 mm): D8 のフットプリント テキスト ( K )
    @(83.9000 mm, 127.8860 mm): 円 of D8 、f.silkscreen 上
[silk_overlap]: シルクスクリーンのオーバーラップ
    ルール: 基板の設定のシルクスクリーンの制約; warning
    @(120.2569 mm, 125.4860 mm): D6 のフットプリント テキスト ( OUT → )
    @(119.3043 mm, 126.0360 mm): D6のリファレンスフィールド
[silk_overlap]: シルクスクリーンのオーバーラップ
    ルール: 基板の設定のシルクスクリーンの制約; warning
    @(100.0000 mm, 92.0000 mm): 基板上のテキスト 'IR BLASTER V2 SMD' ( f.silkscreen 上)
    @(106.0000 mm, 93.0000 mm): TP2のリファレンスフィールド
[silk_overlap]: シルクスクリーンのオーバーラップ
    ルール: 基板の設定のシルクスクリーンの制約; warning
    @(112.8957 mm, 70.2640 mm): D2のリファレンスフィールド
    @(111.9431 mm, 69.7140 mm): D2 のフットプリント テキスト ( OUT → )
[silk_overlap]: シルクスクリーンのオーバーラップ
    ルール: 基板の設定のシルクスクリーンの制約; warning
    @(125.4860 mm, 79.7431 mm): D3 のフットプリント テキスト ( OUT → )
    @(126.0360 mm, 80.6957 mm): D3のリファレンスフィールド
[silk_overlap]: シルクスクリーンのオーバーラップ
    ルール: 基板の設定のシルクスクリーンの制約; warning
    @(129.7360 mm, 112.8957 mm): D5のリファレンスフィールド
    @(130.2860 mm, 111.9431 mm): D5 のフットプリント テキスト ( OUT → )
[silk_overlap]: シルクスクリーンのオーバーラップ
    ルール: 基板の設定のシルクスクリーンの制約; warning
    @(127.5859 mm, 119.1599 mm): D5 のフットプリント テキスト ( K )
    @(127.8860 mm, 116.1000 mm): 円 of D5 、f.silkscreen 上
[silk_overlap]: シルクスクリーンのオーバーラップ
    ルール: 基板の設定のシルクスクリーンの制約; warning
    @(108.4500 mm, 115.2000 mm): 矩形 of RPD 、f.silkscreen 上
    @(109.3000 mm, 116.0000 mm): RPDのリファレンスフィールド
[silk_overlap]: シルクスクリーンのオーバーラップ
    ルール: 基板の設定のシルクスクリーンの制約; warning
    @(94.0000 mm, 93.0000 mm): TP1のリファレンスフィールド
    @(100.0000 mm, 92.0000 mm): 基板上のテキスト 'IR BLASTER V2 SMD' ( f.silkscreen 上)
[silk_overlap]: シルクスクリーンのオーバーラップ
    ルール: 基板の設定のシルクスクリーンの制約; warning
    @(96.0000 mm, 104.0000 mm): TP3の値フィールド ( IR_TX )
    @(94.0000 mm, 106.0000 mm): 円 of Cbulk 、f.silkscreen 上
[silk_overlap]: シルクスクリーンのオーバーラップ
    ルール: 基板の設定のシルクスクリーンの制約; warning
    @(73.9640 mm, 119.3043 mm): D9のリファレンスフィールド
    @(74.5140 mm, 120.2569 mm): D9 のフットプリント テキスト ( OUT → )
[silk_overlap]: シルクスクリーンのオーバーラップ
    ルール: 基板の設定のシルクスクリーンの制約; warning
    @(69.7140 mm, 88.0569 mm): D11 のフットプリント テキスト ( OUT → )
    @(70.2640 mm, 87.1043 mm): D11のリファレンスフィールド
[silk_overlap]: シルクスクリーンのオーバーラップ
    ルール: 基板の設定のシルクスクリーンの制約; warning
    @(80.6957 mm, 73.9640 mm): D12のリファレンスフィールド
    @(79.7431 mm, 74.5140 mm): D12 のフットプリント テキスト ( OUT → )
[nonmirrored_text_on_back_layer]: 裏面レイヤーの非ミラーテキスト
    ローカル オーバーライド; warning
    @(87.3000 mm, 69.8000 mm): J1のリファレンスフィールド
[nonmirrored_text_on_back_layer]: 裏面レイヤーの非ミラーテキスト
    ローカル オーバーライド; warning
    @(112.7000 mm, 69.8000 mm): J2のリファレンスフィールド

** Found 19 unconnected pads **
[unconnected_items]: アイテム間の接続が見つからない
    ローカル オーバーライド; error
    @(79.8000 mm, 100.0000 mm): パッド 1 [+5V] - R10 ( F.Cu 上)
    @(82.5058 mm, 110.1000 mm): パッド 1 [+5V] - R9 ( F.Cu 上)
[unconnected_items]: アイテム間の接続が見つからない
    ローカル オーバーライド; error
    @(82.5058 mm, 89.9000 mm): パッド 1 [+5V] - R11 ( F.Cu 上)
    @(79.8000 mm, 100.0000 mm): パッド 1 [+5V] - R10 ( F.Cu 上)
[unconnected_items]: アイテム間の接続が見つからない
    ローカル オーバーライド; error
    @(82.5058 mm, 110.1000 mm): パッド 1 [+5V] - R9 ( F.Cu 上)
    @(87.3000 mm, 117.7200 mm): PTHパッド 19 [+5V] (J1)
[unconnected_items]: アイテム間の接続が見つからない
    ローカル オーバーライド; error
    @(82.5058 mm, 110.1000 mm): パッド 1 [+5V] - R9 ( F.Cu 上)
    @(91.5000 mm, 106.0000 mm): PTHパッド 1 [+5V] (Cbulk)
[unconnected_items]: アイテム間の接続が見つからない
    ローカル オーバーライド; error
    @(87.3000 mm, 117.7200 mm): PTHパッド 19 [+5V] (J1)
    @(89.9000 mm, 117.4942 mm): パッド 1 [+5V] - R8 ( F.Cu 上)
[unconnected_items]: アイテム間の接続が見つからない
    ローカル オーバーライド; error
    @(93.4000 mm, 88.5688 mm): パッド 1 [+5V] - R12 ( F.Cu 上)
    @(94.0000 mm, 95.0000 mm): PTHパッド 1 [+5V] (TP1)
[unconnected_items]: アイテム間の接続が見つからない
    ローカル オーバーライド; error
    @(100.0000 mm, 120.2000 mm): パッド 1 [+5V] - R7 ( F.Cu 上)
    @(89.9000 mm, 117.4942 mm): パッド 1 [+5V] - R8 ( F.Cu 上)
[unconnected_items]: アイテム間の接続が見つからない
    ローカル オーバーライド; error
    @(100.0000 mm, 120.2000 mm): パッド 1 [+5V] - R7 ( F.Cu 上)
    @(110.1000 mm, 117.4942 mm): パッド 1 [+5V] - R6 ( F.Cu 上)
[unconnected_items]: アイテム間の接続が見つからない
    ローカル オーバーライド; error
    @(101.1000 mm, 101.0000 mm): パッド 1 [+5V] - Cdec ( F.Cu 上)
    @(94.0000 mm, 95.0000 mm): PTHパッド 1 [+5V] (TP1)
[unconnected_items]: アイテム間の接続が見つからない
    ローカル オーバーライド; error
    @(101.1000 mm, 101.0000 mm): パッド 1 [+5V] - Cdec ( F.Cu 上)
    @(91.5000 mm, 106.0000 mm): PTHパッド 1 [+5V] (Cbulk)
[unconnected_items]: アイテム間の接続が見つからない
    ローカル オーバーライド; error
    @(106.6000 mm, 88.5688 mm): パッド 1 [+5V] - R2 ( F.Cu 上)
    @(100.0000 mm, 79.8000 mm): パッド 1 [+5V] - R1 ( F.Cu 上)
[unconnected_items]: アイテム間の接続が見つからない
    ローカル オーバーライド; error
    @(110.1000 mm, 117.4942 mm): パッド 1 [+5V] - R6 ( F.Cu 上)
    @(117.4942 mm, 110.1000 mm): パッド 1 [+5V] - R5 ( F.Cu 上)
[unconnected_items]: アイテム間の接続が見つからない
    ローカル オーバーライド; error
    @(116.9920 mm, 90.1900 mm): 配線 [+5V] ( F.Cu 上、長さ: 10.1559 mm )
    @(106.6000 mm, 88.5688 mm): パッド 1 [+5V] - R2 ( F.Cu 上)
[unconnected_items]: アイテム間の接続が見つからない
    ローカル オーバーライド; error
    @(117.4942 mm, 110.1000 mm): パッド 1 [+5V] - R5 ( F.Cu 上)
    @(116.9920 mm, 90.1900 mm): 配線 [+5V] ( F.Cu 上、長さ: 10.1559 mm )
[unconnected_items]: アイテム間の接続が見つからない
    ローカル オーバーライド; error
    @(87.3000 mm, 105.0200 mm): PTHパッド 14 [GND] (J1)
    @(96.5000 mm, 106.0000 mm): PTHパッド 2 [GND] (Cbulk)
[unconnected_items]: アイテム間の接続が見つからない
    ローカル オーバーライド; error
    @(96.5000 mm, 106.0000 mm): PTHパッド 2 [GND] (Cbulk)
    @(99.0000 mm, 116.9500 mm): ビア [GND] (F.Cu - B.Cu 上)
[unconnected_items]: アイテム間の接続が見つからない
    ローカル オーバーライド; error
    @(99.0000 mm, 116.9500 mm): ビア [GND] (F.Cu - B.Cu 上)
    @(108.0000 mm, 116.9500 mm): ビア [GND] (F.Cu - B.Cu 上)
[unconnected_items]: アイテム間の接続が見つからない
    ローカル オーバーライド; error
    @(102.9000 mm, 101.0000 mm): ビア [GND] (F.Cu - B.Cu 上)
    @(96.5000 mm, 106.0000 mm): PTHパッド 2 [GND] (Cbulk)
[unconnected_items]: アイテム間の接続が見つからない
    ローカル オーバーライド; error
    @(106.0000 mm, 95.0000 mm): PTHパッド 1 [GND] (TP2)
    @(102.9000 mm, 101.0000 mm): ビア [GND] (F.Cu - B.Cu 上)

** Found 0 Footprint errors **

** End of Report **

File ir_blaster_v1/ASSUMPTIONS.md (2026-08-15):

# Assumptions and open confirmations

- 写真のボードをESP32-DevKitC V4相当38ピンとして扱った。クローン差は実物で要確認。
- 外径は写真の70 mm級を基に、LED/抵抗/ヘッダー間隔を確保して74.0 mmとした。
- LED傾斜はJLCPCBに依頼せず、ユーザーが手はんだで決める。
- ソケット完成穴は1.0 mm。購入予定ソケットの角ピン対角寸法+0.1 mm以上か確認する。
- Q1は試作同等性のため維持したが、3.3 VでのRDS(on)最大保証はない。
- JLC/LCSC在庫番号は発注直前に固定する。未確認番号を推測して記入していない。

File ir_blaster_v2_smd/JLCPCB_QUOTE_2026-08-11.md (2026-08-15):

# JLCPCB preliminary quote — 2026-08-11

Configuration: 74 x 74 mm, 2-layer FR-4, white solder mask, 5 boards, Economic PCBA, top-side SMT.

## Quote observed in JLCPCB portal

- PCB: USD 2.00
- Economic PCBA: USD 12.37
  - Setup fee: USD 8.18
  - Stencil: USD 1.53
  - Components (5 BOM line items / 80 placed parts): USD 1.50
  - SMT assembly: USD 0.26
  - Nitrogen reflow: USD 0.90
- Total: USD 14.37
- Shipping and tax: not included in the final PCBA total above
- Separate PCB-only screen showed an estimated USD 8.95 UPS shipping charge at the time of the check.

## Confirmed JLCPCB parts

| Function | Designators | JLC/LCSC | Part | Portal component cost for 5 boards |
|---|---|---:|---|---:|
| LED current resistors | R1-R12 | C17901 | 100 ohm, 1206, 250 mW | USD 0.7380 |
| Gate resistor | RG | C22962 | 220 ohm, 0603 | USD 0.0425 |
| Gate pull-down | RPD | C25804 | 10 kohm, 0603 | USD 0.2055 |
| MOSFET | Q1 | C20917 | AO3400A, SOT-23 | USD 0.4205 |
| Decoupling capacitor | Cdec | C14663 | 100 nF, 50 V, X7R, 0603 | USD 0.0925 |

LEDs, ESP32 pin sockets, and the 1000 uF bulk capacitor are excluded from PCBA and intended for user hand soldering in this cost-optimized quote.

## Important

This is a preliminary cost check, not an order release. JLCPCB accepted the Gerber/BOM/CPL and matched all 16 designators groups. The generated PCB still needs a final KiCad connectivity/zone-fill review and visual placement review before purchase.

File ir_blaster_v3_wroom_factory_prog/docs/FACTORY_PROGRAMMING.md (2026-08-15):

# Factory programming

## Interfaces

The same six nets are available on both interfaces:

| Order | Pogo pad | J_PROG | Function |
|---:|---|---|---|
| 1 | TP_PROG_3V3 | pin 1 | 3.3 V supply/measurement |
| 2 | TP_PROG_GND | pin 2 | Ground |
| 3 | TP_PROG_TX | pin 3 | ESP32 TXD0 |
| 4 | TP_PROG_RX | pin 4 | ESP32 RXD0 |
| 5 | TP_PROG_EN | pin 5 | Chip enable/reset |
| 6 | TP_PROG_IO0 | pin 6 | Boot-mode control |

Connect programmer TX to board RX and programmer RX to board TX.

## Recommended safe connection

When the finished board is powered through USB-C, connect only programmer GND,
TX, RX, EN and IO0. Leave the programmer's 3V3 output disconnected. This avoids
two regulators driving the same 3.3 V rail.

To power the entire board from the programmer instead, disconnect USB-C first.
The programmer's 3.3 V output must support ESP32 Wi-Fi current peaks and the
load of the rest of the board. A low-current USB-UART adapter may brown out or
be damaged and must not be assumed suitable.

## Manual download sequence

1. Remove all other power sources or use the five-wire connection above.
2. Connect GND, TX/RX crossed, EN and IO0.
3. Hold IO0 low.
4. Pulse EN low, then release EN high.
5. Release IO0 after the ROM bootloader starts.
6. Flash with `esptool` or an equivalent ESP32 programmer.
7. Reset with IO0 high/floating to boot the application.

Do not leave EN or IO0 driven above 3.3 V. The programmer and board must share
ground before UART or control signals are applied.

## Fixture notes

- Six bottom pads are in a straight 1x6 line at 3.81 mm pitch.
- Exposed copper diameter: 2.4 mm.
- Pad 1 is rectangular and marked `PIN1`/`3V3` on bottom silkscreen.
- Use spring probes appropriate for flat ENIG/HASL pads.
- Add mechanical locating pins to the fixture; do not use pogo pins alone to
  locate the PCB.

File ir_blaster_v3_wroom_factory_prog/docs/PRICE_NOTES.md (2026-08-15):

# Price notes

The programming interface itself has almost no PCBA assembly cost:

- the pogo pads are copper features in the PCB artwork;
- J_PROG is DNP and absent from the production BOM/CPL;
- the extra through holes normally do not create a separate assembly charge.

The expected increase comes mainly from replacing the user-supplied DevKit with
an assembled ESP32-WROOM-32E-N16 module. JLCPCB lists C701343 as an Extended
part for Standard PCBA, so the quote can include the module price, an Extended-
part loading fee and any module inspection/X-ray requirements. Shipping, tax,
stencil and fixture costs are separate.

## 2026-08-12 live cart quote

The V3 Gerbers, BOM and corrected CPL were uploaded to JLCPCB as a five-piece,
top-side Standard PCBA order. JLCPCB detected a 2-layer 74 x 74 mm board and
matched U1 to C701343 (ESP32-WROOM-32E-N16, Extended). The component-placement
viewer was checked after correcting the CPL Y-coordinate sign.

| Item | Live quote |
|---|---:|
| PCB fabrication, five pieces | US$2.00 |
| Standard PCBA | US$69.50 |
| Setup fee | US$25.56 |
| Stencil | US$8.21 |
| Panel / large-size surcharge | US$0.00 |
| Five ESP32 modules | US$25.13 |
| Feeder loading | US$1.53 |
| SMT assembly | US$0.38 |
| X-ray inspection | US$8.20 |
| Packaging | US$0.49 |
| PCB + PCBA merchandise total | **US$71.50** |
| Current shipping estimate | US$8.95 |
| Current cart subtotal | **US$80.45** |

The selected normal build time was 24 hours for PCB fabrication and 3–4 days
for assembly. The cart showed 497.70 g. Shipping is an estimate and taxes,
currency conversion, coupons and any later engineering-review adjustments are
not included. No separate fixture or panel charge appeared in this live quote.
The order was added to the cart but was not submitted or paid.

## 2026-08-11 working estimate (superseded by the live quote above)

JLCPCB currently identifies C701343 as Extended, Standard-PCBA-only, and says an
assembly support fixture is required. The displayed module price was US$4.6528
at quantity 1+, with 15,984 units shown in stock. JLCPCB's published Standard
PCBA charges include US$25 one-side setup, US$7.86 one-side stencil, US$1.50 per
loaded Basic/Extended part, US$0.0016 per solder joint, and X-ray at US$1.57 per
piece for 1–10 pieces.

For five milestone boards with only U1 assembled, the published line items give
this lower-bound estimate:

| Item | Estimate |
|---|---:|
| Standard PCBA one-side setup | US$25.00 |
| Stencil | US$7.86 |
| One feeder load | US$1.50 |
| Five ESP32 modules | US$23.26 |
| X-ray, five pieces | US$7.85 |
| Placement/joint charge | about US$0.31 |
| Published-subtotal lower bound | about **US$65.79** |

PCB fabrication, the module support fixture, component attrition, packing,
shipping and tax are not included. The likely checkout total is therefore above
US$65.79. X-ray is a provisional assumption because the module has hidden
soldering areas; if JLCPCB does not apply it, subtract US$7.85 (US$57.94 before
the excluded items). A US$7.81 panel charge may also appear if JLCPCB requires
assembly panelization. The module fixture price is not published on the part
page and can only be confirmed by the live order review.

This milestone quote is not the final full-product price because USB-C power
and IR output components are not yet present.

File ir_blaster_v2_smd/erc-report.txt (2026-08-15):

ERC レポート (2026-08-11T20:12:23+0900, エンコーディング UTF8)

***** シート /

 ** ERC メッセージ: 0  エラー 0  警告 0

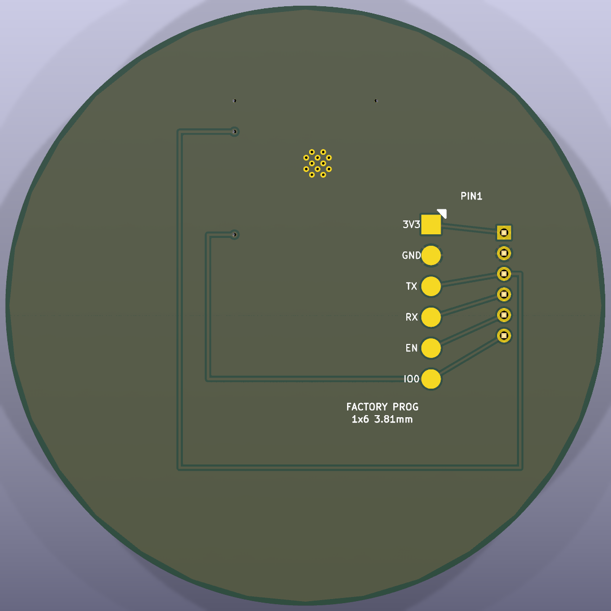
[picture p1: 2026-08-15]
ir_blaster_v3_wroom_factory_prog/preview/bottom.png

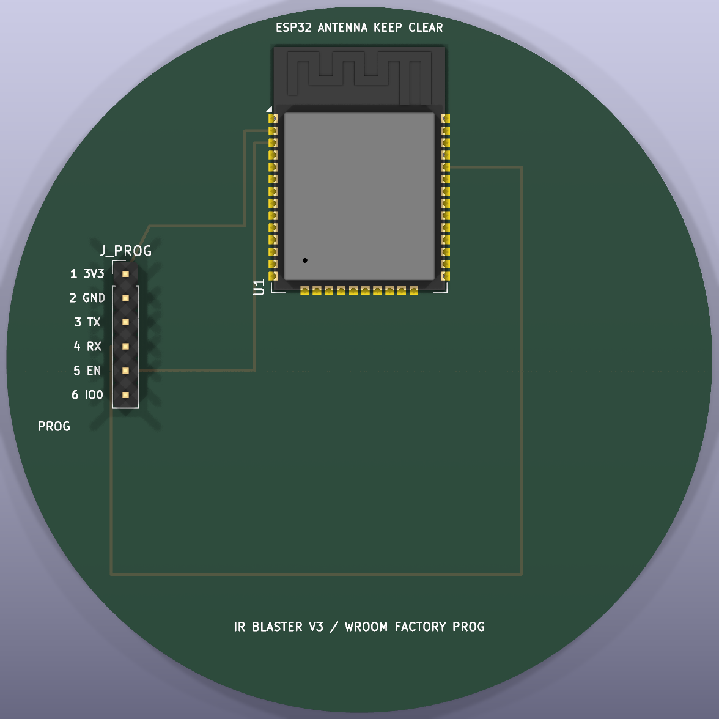
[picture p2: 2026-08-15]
ir_blaster_v3_wroom_factory_prog/preview/top.png

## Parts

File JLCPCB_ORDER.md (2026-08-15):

# JLCPCB 注文チェックリスト

## アップロード

`manufacturing/m5_ir_blaster_revA_gerbers.zip`

## 設定

- FR-4
- 2 Layers
- 52 × 40 mm
- 5 pcs
- 1.6 mm
- 1 oz
- Green solder mask
- White silkscreen
- LeadFree HASL
- Tented vias
- PCB Assembly: 必要に応じて選択
- Panel by JLCPCB: No

### 表面実装だけを依頼する場合

- PCBAタイプ: Economic
- 組立面: Top
- PCBA数量: 5
- BOM: `assembly/BOM_JLCPCB_SMD_ONLY.csv`
- CPL: `assembly/CPL_JLCPCB_SMD_ONLY.csv`
- J1、D1〜D4、U2は実装データから除外済み（手はんだ用）
- R3〜R5は33Ω・0805・0.5W以上または同等の耐パルス品を指定する
- ステンシルは注文しない

## Gerber Viewerで見る場所

- 外形が52 × 40 mmの長方形
- 四隅に3.2 mmの取付穴
- 上辺側に5 mm IR LEDが3個
- 左側に3ピンIR受信器
- 下辺側に4ピンJSTコネクタ
- F.Cu / B.Cu / F.Mask / B.Mask / F.Silkscreen / Edge.Cuts が認識されている
- PTHとNPTHのドリルが認識されている

## 到着後

最初は電流制限付き電源を使い、部品を付ける前に5 V-GND間の短絡がないことを確認します。
次にU1とC1/C2だけを実装して3.3 Vを確認し、その後IR受信部、最後に送信部の順で実装すると安全です。

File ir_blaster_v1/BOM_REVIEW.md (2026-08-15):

# BOM / JLCPCB review

確認日: 2026-08-11。JLCPCBの在庫は変動するため、発注画面で再確認してください。

| 部品 | MPN | 状態 | 組立方法 | 代替 |
|---|---|---|---|---|
| Wide IR LED ×4 | OptoSupply OSI5LA7WA1B | exact partのJLC在庫を確認できず | **DNP / user solder** | 無断置換しない |
| Narrow IR LED ×8 | OptoSupply OSI5LA5A33A-B | exact partのJLC在庫を確認できず | **DNP / user solder** | 無断置換しない |
| ESP32 socket ×2 | 1×19, 2.54 mm | ユーザー手配 | **DNP / user solder** | 実物のピン寸法で選定 |
| Q1 | ISAHAYA INK021ABS1-T112 | exact partのJLC在庫を確認できず | Global sourcing / consigned候補 | 3.3 V保証品は次版候補 |
| R1–R12 | 100 Ω axial 1/4 W | JLCにTHT抵抗カテゴリあり。発注時にMPN固定 | Wave/manual candidate | 値・定格・外形一致品のみ |
| RG | 220 Ω axial 1/4 W | 同上 | Wave/manual candidate | 同上 |
| RPD | 10 kΩ axial 1/4 W | 同上 | Wave/manual candidate | 同上 |
| Cbulk | 1000 µF, 10 V以上, radial P5.0 | 発注時に外径8 mm以下の在庫品を固定 | Wave/manual candidate | 容量・耐圧・極性・径を維持 |
| Cdec | 100 nF leaded P2.54 | 発注時に在庫品を固定 | Wave/manual candidate | THT維持。SMD化は別承認 |

JLCPCBの公開FAQでは、parts libraryで`wave soldering`指定されたTHTを手作業で組立可能としています。顧客支給部品（consigned parts）も受け付けています。ただしLEDの指定角度は標準保証として確認できないため、本注文データからLEDを除外しています。

参考:

- https://jlcpcb.com/help/article/pcb-assembly-faqs
- https://jlcpcb.com/help/article/jlcpcb-supported-personalized-services
- https://jlcpcb.com/help/article/difference-and-tolerance-explanation-between-via-and-pad-holes

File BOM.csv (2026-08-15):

Reference | Qty | Value | Description | Footprint / notes
J1 | 1 | JST-PH 4-pin | Grove/M5 cable connector | 2.00 mm vertical
D1 D2 D3 | 3 | 940 nm IR LED | High-output 5 mm IR emitter | Vishay TSAL6200 or equivalent
D4 | 1 | Visible LED | TX activity indicator | 3 mm through-hole
R1 | 1 | 100 ohm | MOSFET gate resistor | 0805
R2 | 1 | 100 kohm | MOSFET gate pull-down | 0805
R3 R4 R5 | 3 | 33 ohm | IR LED current limiting 0.5 W pulse-rated | 0805 high-power
R6 | 1 | 100 ohm | IR receiver supply filter | 0805
R7 | 1 | 1 kohm | Visible LED current limiting | 0805
Q1 | 1 | AO3400A | N-channel logic-level MOSFET | SOT-23
U1 | 1 | MCP1700-3302 | 3.3 V LDO regulator | SOT-23
U2 | 1 | TSOP38238 | 38 kHz IR receiver | Through-hole 3-pin 2.54 mm
C1 C2 | 2 | 1 uF 10 V | LDO input/output capacitors | 0805 X7R
C3 | 1 | 4.7 uF 10 V | IR receiver supply filter | 0805 X7R
C4 | 1 | 100 nF | IR receiver local bypass | 0805 X7R
H1 H2 H3 H4 | 4 | M3 mounting hole | NPTH | 3.2 mm drill

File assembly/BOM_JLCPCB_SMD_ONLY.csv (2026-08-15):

Comment | Designator | Footprint | LCSC Part #
1uF 10V X7R | C1,C2 | 0805
4.7uF 10V X7R | C3 | 0805
100nF 50V X7R | C4 | 0805
AO3400A | Q1 | SOT-23-3 | C20917
100R 1% | R1,R6 | 0805
100k 1% | R2 | 0805
33R 0.5W pulse-rated | R3,R4,R5 | 0805
1k 1% | R7 | 0805
MCP1700T-3302E/TT | U1 | SOT-23-3 | C39051

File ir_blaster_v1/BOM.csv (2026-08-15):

Reference | Qty | Value | Footprint | Manufacturer | MPN | JLC/LCSC | Assembly method | Notes
D1,D4,D7,D10 | 4 | 940nm IR LED wide 100° | OSI5LA7WA1B | OptoSupply | OSI5LA7WA1B | Not verified in live JLC library | THT / DNP | User hand solder; pin 1=A, 2=K
D2,D3,D5,D6,D8,D9,D11,D12 | 8 | 940nm IR LED narrow 30° | OSI5LA5A33A-B | OptoSupply | OSI5LA5A33A-B | Not verified in live JLC library | THT / DNP | User hand solder; pin 1=A, 2=K
R1-R12 | 12 | 100R 0.25W | R_Axial_DIN0207_P10.16mm | TBD | 100 ohm axial 1/4W | Select exact stocked wave-solder part at order | THT / wave/manual | PCBA candidate
RG | 1 | 220R 0.25W | R_Axial_DIN0207_P10.16mm | TBD | 220 ohm axial 1/4W | Select exact stocked wave-solder part at order | THT / wave/manual | PCBA candidate
RPD | 1 | 10k 0.25W | R_Axial_DIN0207_P10.16mm | TBD | 10k axial 1/4W | Select exact stocked wave-solder part at order | THT / wave/manual | PCBA candidate
Q1 | 1 | N-MOSFET | INK021ABS1_TO92S | ISAHAYA Electronics | INK021ABS1-T112 | No exact JLC result verified | THT / global sourcing or consigned | Do not substitute without approval; 1=S 2=D 3=G
Cbulk | 1 | 1000uF 10V | Radial P5.0mm | TBD | 1000uF >=10V radial | Select exact stocked wave-solder part at order | THT / wave/manual | Verify diameter <=8mm
Cdec | 1 | 100nF | Radial P2.54mm | TBD | 100nF leaded ceramic | Select exact stocked wave-solder part at order | THT / wave/manual | PCBA candidate
J1,J2 | 2 | 1x19 2.54mm socket | ESP32_DevKitC_V4_1x19 | User supplied | 2.54mm female socket 1x19 | N/A | THT / DNP | User hand solder; 25.40mm row spacing

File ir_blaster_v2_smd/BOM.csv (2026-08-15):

Reference | Qty | Value | Footprint | Manufacturer | MPN | JLC/LCSC | Assembly method | Notes
D1,D4,D7,D10 | 4 | 940nm IR LED wide 100° | OSI5LA7WA1B | OptoSupply | OSI5LA7WA1B | DNP | THT / DNP | User hand solder; pin 1=A, 2=K
D2,D3,D5,D6,D8,D9,D11,D12 | 8 | 940nm IR LED narrow 30° | OSI5LA5A33A-B | OptoSupply | OSI5LA5A33A-B | DNP | THT / DNP | User hand solder; pin 1=A, 2=K
R1-R12 | 12 | 100R 0.25W | R_1206_3216Metric | UNI-ROYAL | 1206W4F1000T5E | C17901 | SMT / top | 1206 selected for pulse-power margin
RG | 1 | 220R | R_0603_1608Metric | UNI-ROYAL | 0603WAF2200T5E | C22962 | SMT / top | Gate series resistor
RPD | 1 | 10k | R_0603_1608Metric | UNI-ROYAL | 0603WAF1002T5E | C25804 | SMT / top | Gate pull-down
Q1 | 1 | AO3400A | SOT-23 | Alpha & Omega Semiconductor | AO3400A | C20917 | SMT / top | Logic-level N-MOSFET; 1=G 2=S 3=D
Cdec | 1 | 100nF 50V X7R | C_0603_1608Metric | Samsung Electro-Mechanics | CL10B104KB8NNNC | C14663 | SMT / top | Local decoupling
Cbulk | 1 | 1000uF 10V | Radial P5.0mm | TBD | 1000uF >=10V radial | DNP | THT / DNP | Cost option: user hand solder; diameter <=8mm
J1,J2 | 2 | 1x19 2.54mm socket | ESP32_DevKitC_V4_1x19 | User supplied | 2.54mm female socket 1x19 | DNP | THT / DNP | User hand solder; 25.40mm row spacing

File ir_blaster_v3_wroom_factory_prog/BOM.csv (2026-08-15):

Reference | Qty | Value | Manufacturer | MPN | JLC/LCSC | Assembly | Notes
U1 | 1 | ESP32-WROOM-32E-N16 | Espressif Systems | ESP32-WROOM-32E-N16 | C701343 | SMT / Standard PCBA | 16MB flash; X-ray required by JLCPCB
J_PROG | 1 | 1x6 2.54mm male header | Samtec-compatible | TSW-106-07-G-S compatible | DNP | DNP | 1.0mm drill, 1.7mm pad
TP_PROG_* | 6 | 2.4mm bottom pogo pads | PCB feature | N/A | N/A | PCB only | 1x6 straight, 3.81mm pitch

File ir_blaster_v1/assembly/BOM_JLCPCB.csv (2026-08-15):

Comment | Designator | Footprint | LCSC Part #
100R 0.25W | R1-R12 | R_Axial_DIN0207_P10.16mm | TBD_AT_ORDER
220R 0.25W | RG | R_Axial_DIN0207_P10.16mm | TBD_AT_ORDER
10k 0.25W | RPD | R_Axial_DIN0207_P10.16mm | TBD_AT_ORDER
N-MOSFET | Q1 | INK021ABS1_TO92S | TBD_AT_ORDER
1000uF 10V | Cbulk | Radial P5.0mm | TBD_AT_ORDER
100nF | Cdec | Radial P2.54mm | TBD_AT_ORDER

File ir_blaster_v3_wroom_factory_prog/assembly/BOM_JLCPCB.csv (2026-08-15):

Comment | Designator | Footprint | LCSC Part #
ESP32-WROOM-32E-N16 | U1 | ESP32-WROOM-32E | C701343

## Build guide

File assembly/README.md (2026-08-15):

# JLCPCB 表面実装データ

このフォルダのBOM/CPLは、表面実装部品だけをJLCPCBへ依頼するためのデータです。

## アップロードするファイル

- BOM: `BOM_JLCPCB_SMD_ONLY.csv`
- CPL: `CPL_JLCPCB_SMD_ONLY.csv`

## JLCPCBで実装する部品

- R1〜R7
- C1〜C4
- Q1
- U1

## 自分ではんだ付けするため、BOM/CPLから除外した部品

- J1: JST-PH 4ピン
- D1〜D3: 5mm IR LED
- D4: 3mm表示LED
- U2: TSOP38238（挿入型IR受信器）

## 部品選択時の注意

- Q1はLCSC `C20917`（AO3400A）を指定しています。
- U1はLCSC `C39051`（Microchip MCP1700T-3302E/TT）を指定しています。
- R3〜R5はIR LEDのパルス電流制限抵抗です。通常の0.125W品ではなく、33Ω・0805・0.5W以上または同等の耐パルス品を選びます。該当品がJLCPCB在庫にない場合、この3点だけ未実装にして手はんだします。
- 抵抗・コンデンサのLCSC番号は固定していません。在庫と基本部品区分を見て、JLCPCBの部品選択画面で同等品を選びます。
- CPLの座標はKiCadが出力する基板座標です。部品配置確認画面で、シルクの向きとパッド位置が一致することを必ず確認します。

## 推奨注文設定

- PCBAタイプ: Economic
- 組立面: Top
- PCBA数量: 5
- 部品選択: 顧客による（セルフサービス）
- ステンシル: 注文しない
- Through-hole assembly: なし

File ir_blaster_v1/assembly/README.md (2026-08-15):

# Assembly data

`BOM_JLCPCB.csv` は候補表です。LED D1–D12とESP32ソケットJ1/J2は、ユーザー手はんだ指定のため除外済みです。

この版の残り部品はTHT中心なので、SMT用CPL座標ではなくJLCPCBのwave/manual assembly工程を使います。`TBD_AT_ORDER`のLCSC番号を、注文日の実在庫・外形・耐圧・定格と照合してから置き換えてください。Q1 exact partを調達できない場合は勝手に代替せず、DNPまたはconsignedにします。

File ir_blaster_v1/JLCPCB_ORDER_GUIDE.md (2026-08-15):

# JLCPCB order guide

## PCB

- Upload: `manufacturing/ir_blaster_v1_gerbers.zip`
- Base material: FR-4
- Layers: 2
- Dimensions: 74.0 × 74.0 mm（円形外形をViewerで確認）
- PCB Qty: 5（初回推奨）
- Thickness: 1.6 mm
- Copper weight: 1 oz
- Solder mask: White
- Silkscreen: Black
- Surface finish: LeadFree HASL（好みでENIG）
- Via covering: Tented
- Confirm production file: Yes（初回推奨）

## PCBA

- Assembly side: Top
- LED D1–D12: Do not place / DNP
- ESP32 sockets J1/J2: Do not place / DNP
- Q1: exact MPNをGlobal sourcingまたはconsignedで確保できない場合はDNPに変更
- THT passives: portal上で`wave soldering`またはmanual assembly対象になっているexact partを割当
- `TBD_AT_ORDER`を残したまま注文しない

## Viewerで見る箇所

1. 円形Edge.Cutsが1本で閉じている。
2. LED 12個の各1番穴がA、2番穴がK/共通Drain。
3. ESP32の2列が25.40 mm、各19穴。
4. `USB ↓` と手元ボードのUSB側が一致。
5. Cbulkの`+`表示とBOMの極性が一致。
6. Q1のシルクが左からS/D/G。

## 到着後

LED/ESP32ソケットを付ける前に、5V–GND短絡がないこと、GPIO25–Gate、Drain busの導通を確認します。次に電流制限付き5 V電源で1灯相当から試験し、最後に全灯38 kHzパルスを確認します。

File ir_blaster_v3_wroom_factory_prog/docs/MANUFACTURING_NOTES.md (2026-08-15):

# Manufacturing notes

## PCB

- Shape: circular, 74.0 mm diameter
- Layers: 2
- Thickness: 1.6 mm
- Minimum designed signal clearance: 0.25 mm
- Signal track width: 0.25–0.30 mm
- Standard vias: 0.40 mm drill / 0.80 mm pad
- WROOM thermal vias: 0.30 mm drill / 0.70 mm pad
- Bottom GND copper pour

## Assembly

- U1: ESP32-WROOM-32E-N16, JLC/LCSC C701343
- J_PROG: DNP; user-installed 2.54 mm straight male header if needed
- Pogo pads: bare PCB features, not components

J_PROG uses KiCad's standard `PinHeader_1x06_P2.54mm_Vertical` footprint:
1.00 mm finished hole and 1.70 mm pad. This provides a 0.35 mm annular ring and
accepts common 0.64 mm square pins.

The ESP32 antenna end is placed at the board perimeter. Do not add copper,
components, metal case parts or wiring within the marked antenna keepout in the
full-product merge.

## Release limitation

This package validates the programming-interface architecture only. It must not
be ordered as the final blaster until the remaining power and IR circuitry from
the master specification is integrated and a complete mechanical/3D review is
performed.

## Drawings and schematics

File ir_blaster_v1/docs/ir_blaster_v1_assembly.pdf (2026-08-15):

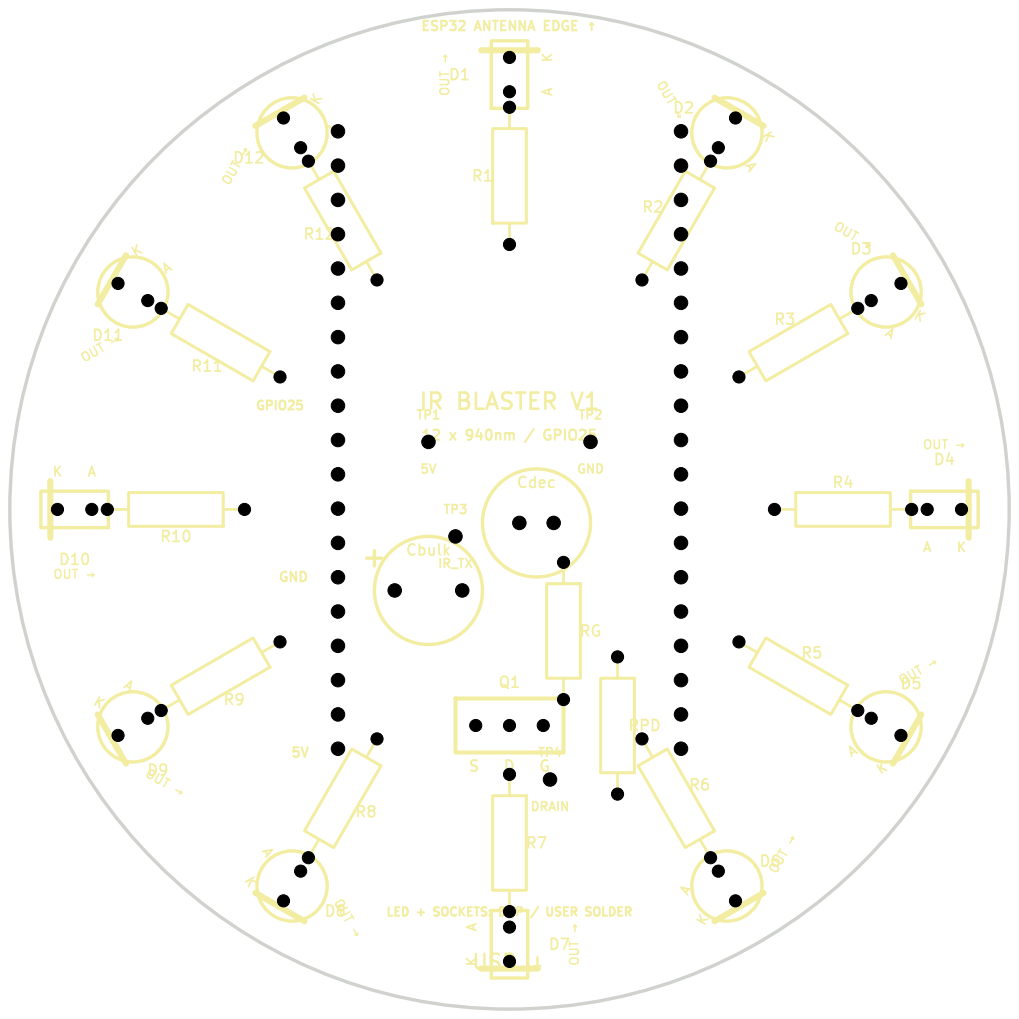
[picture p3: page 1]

A OUT þÿ!’ D5 K OUT þÿ!’ A Cdec

LED + SOCKETS: DNP / USER SOLDER GND

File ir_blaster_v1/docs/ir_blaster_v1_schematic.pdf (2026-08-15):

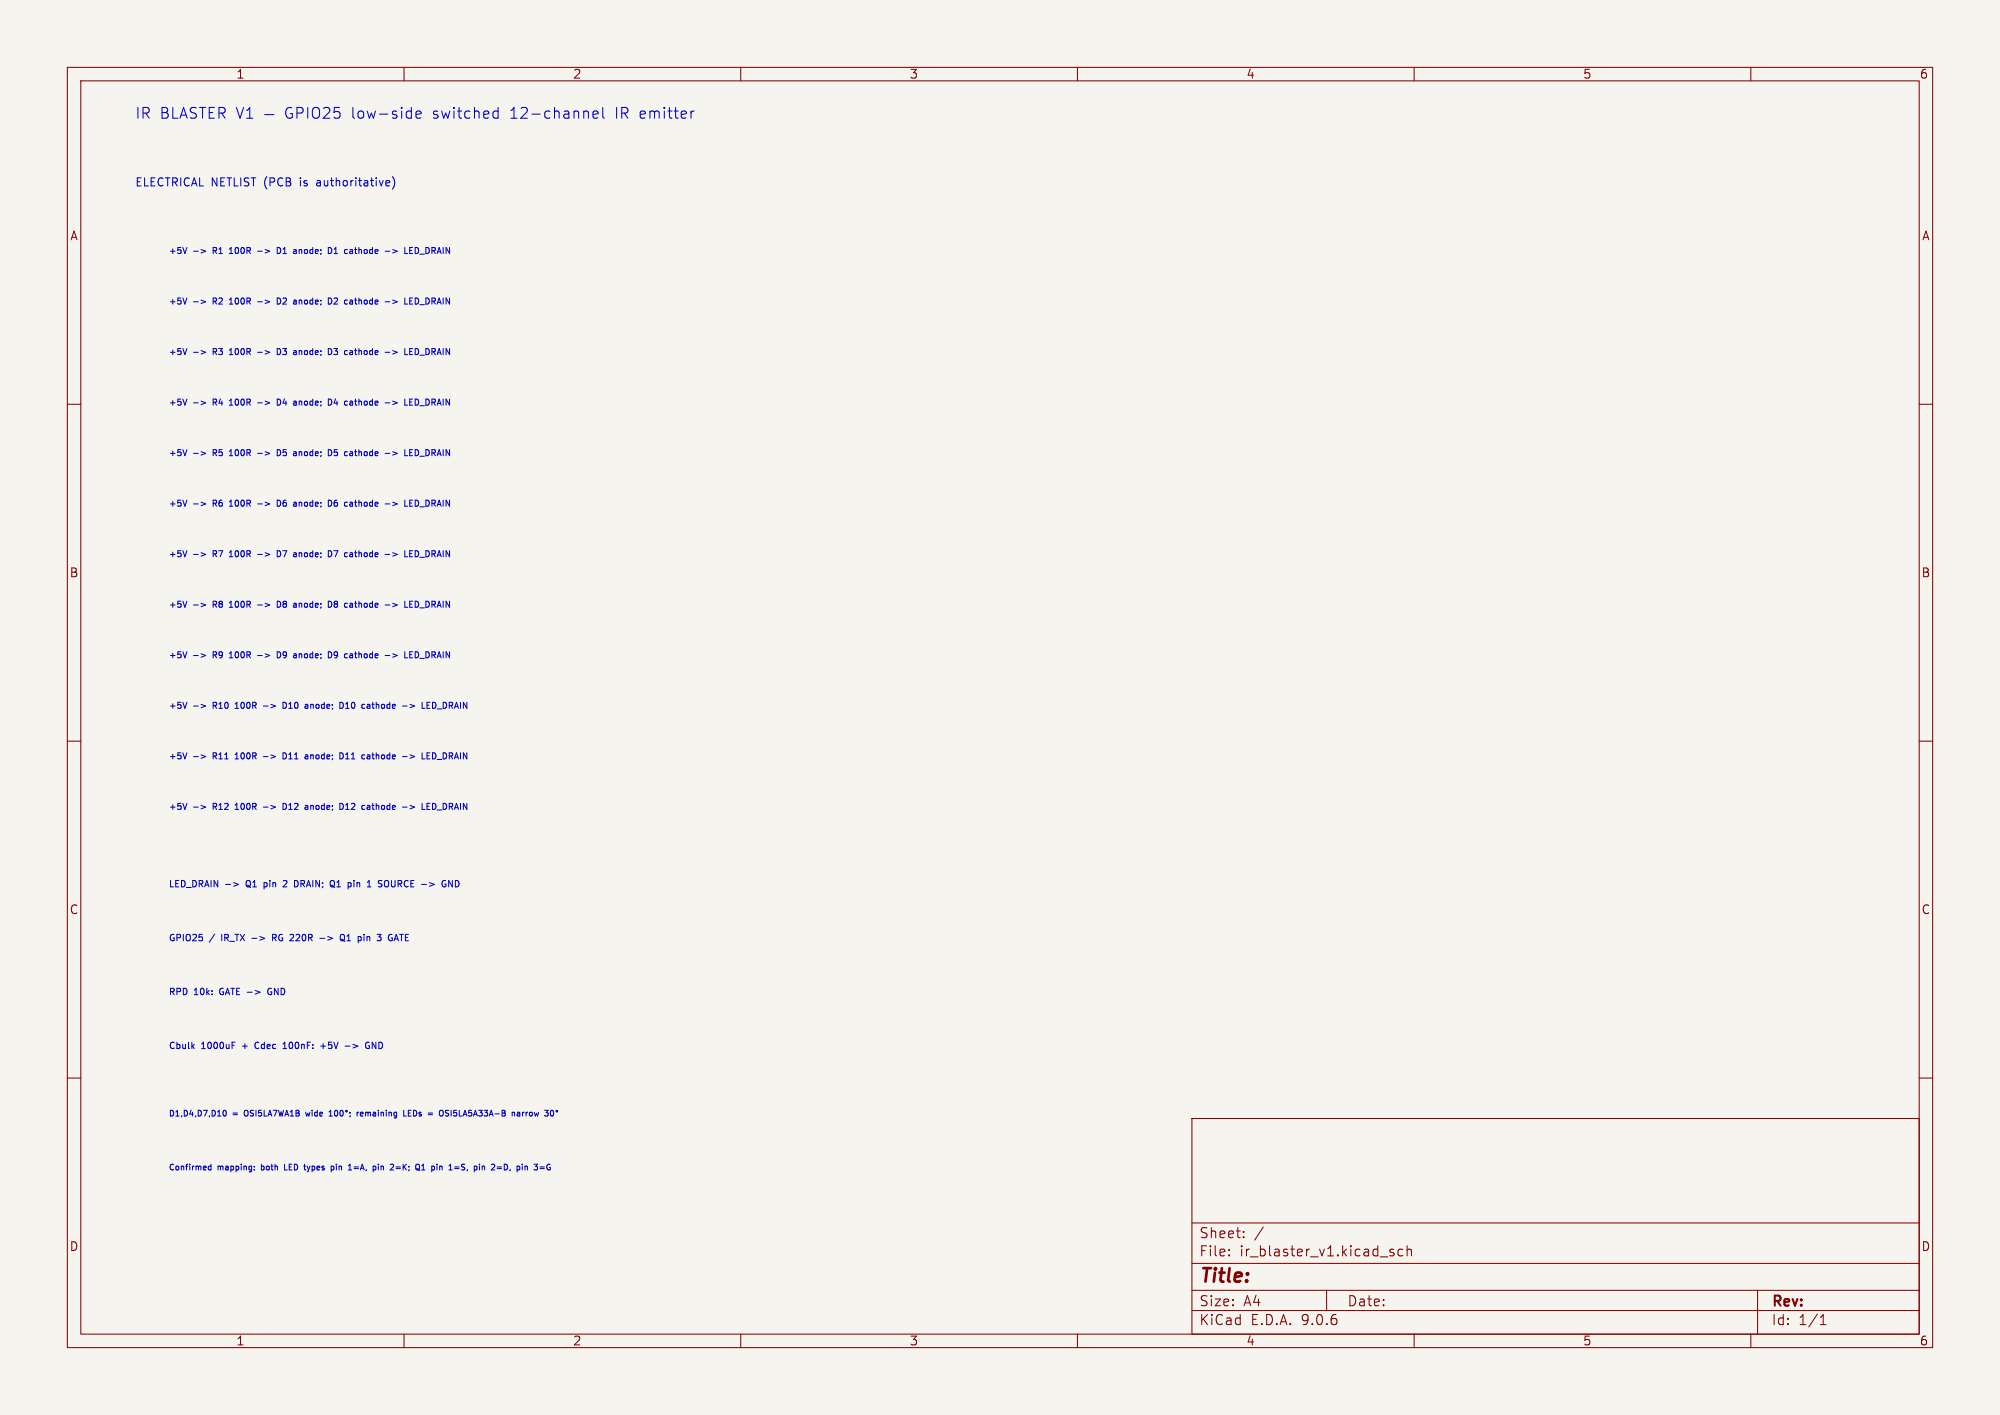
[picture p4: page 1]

Id: 1/1 Title: File: ir_blaster_v1.kicad_sch Sheet: /

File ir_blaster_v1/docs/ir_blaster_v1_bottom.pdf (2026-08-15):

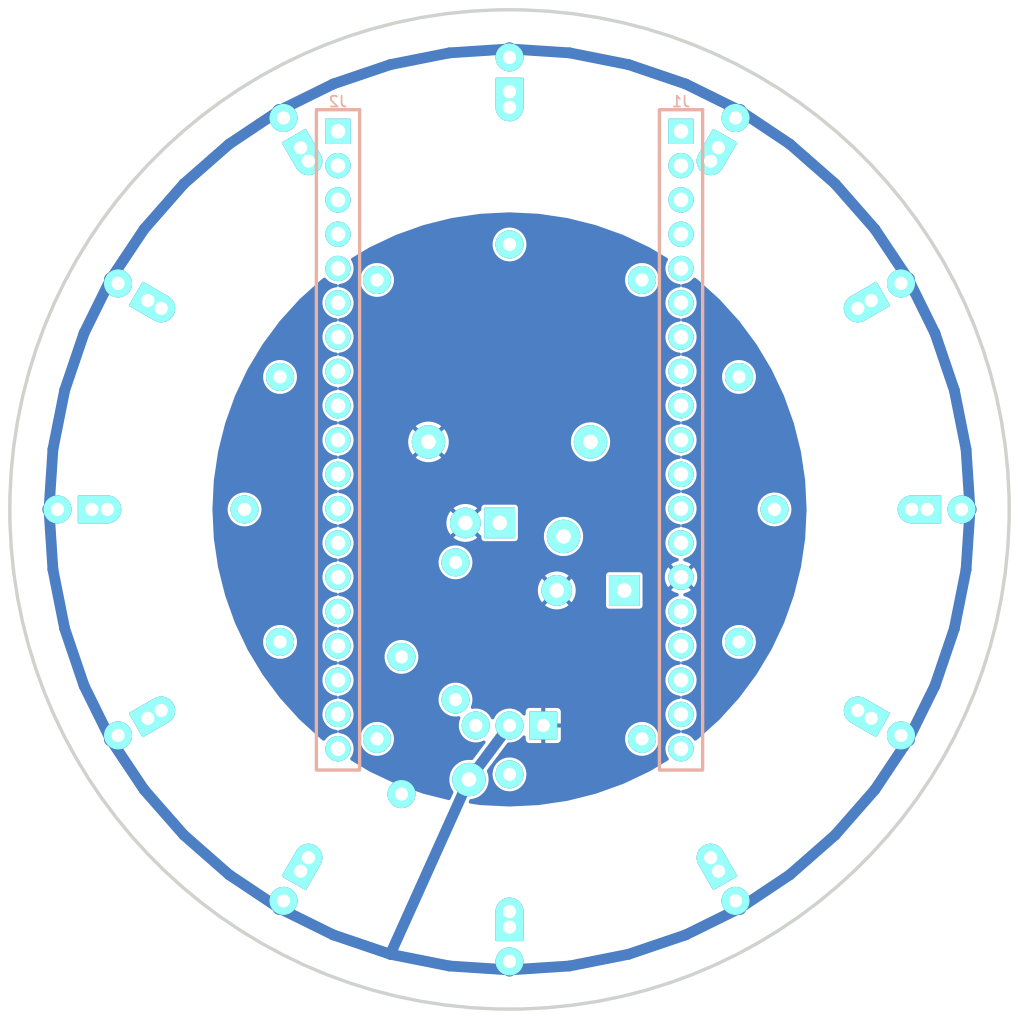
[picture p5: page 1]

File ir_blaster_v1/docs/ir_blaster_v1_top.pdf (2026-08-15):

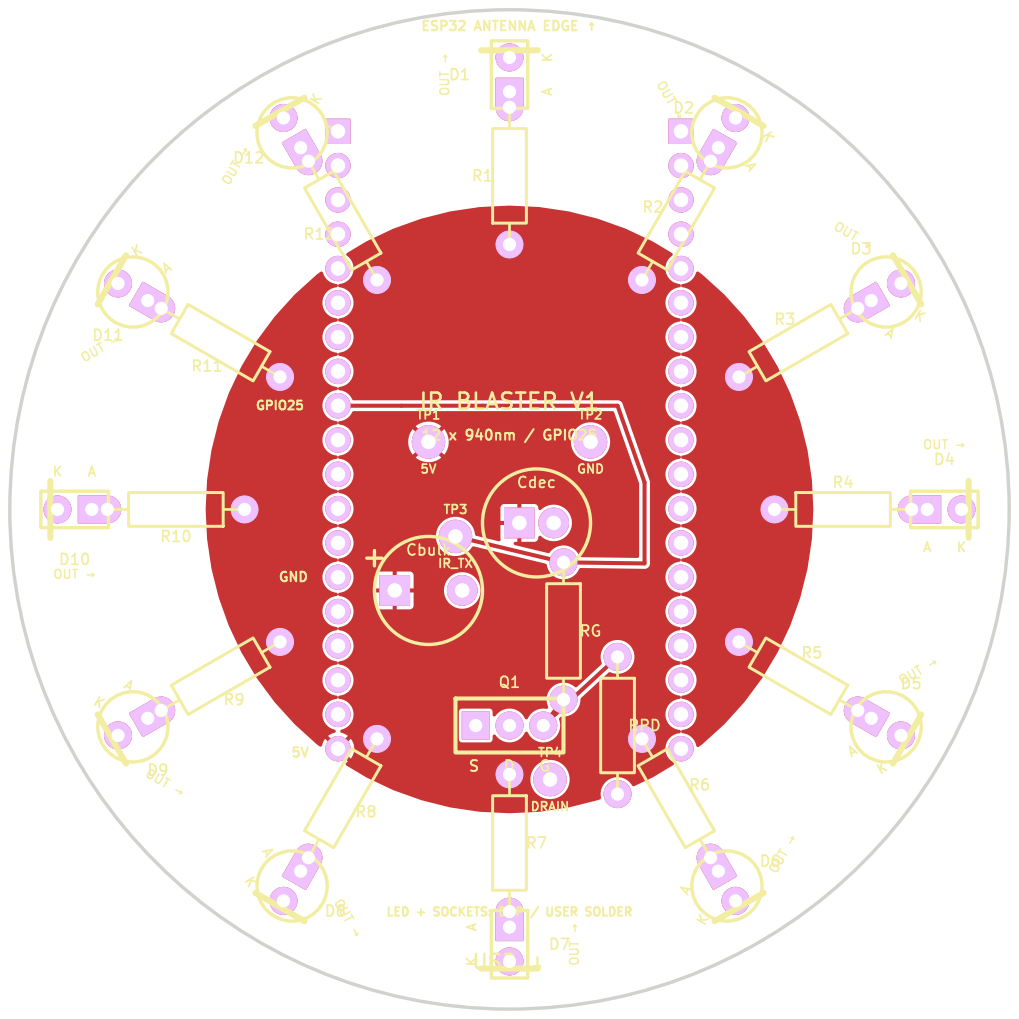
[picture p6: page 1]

A OUT þÿ!’ D5 K OUT þÿ!’ A Cdec

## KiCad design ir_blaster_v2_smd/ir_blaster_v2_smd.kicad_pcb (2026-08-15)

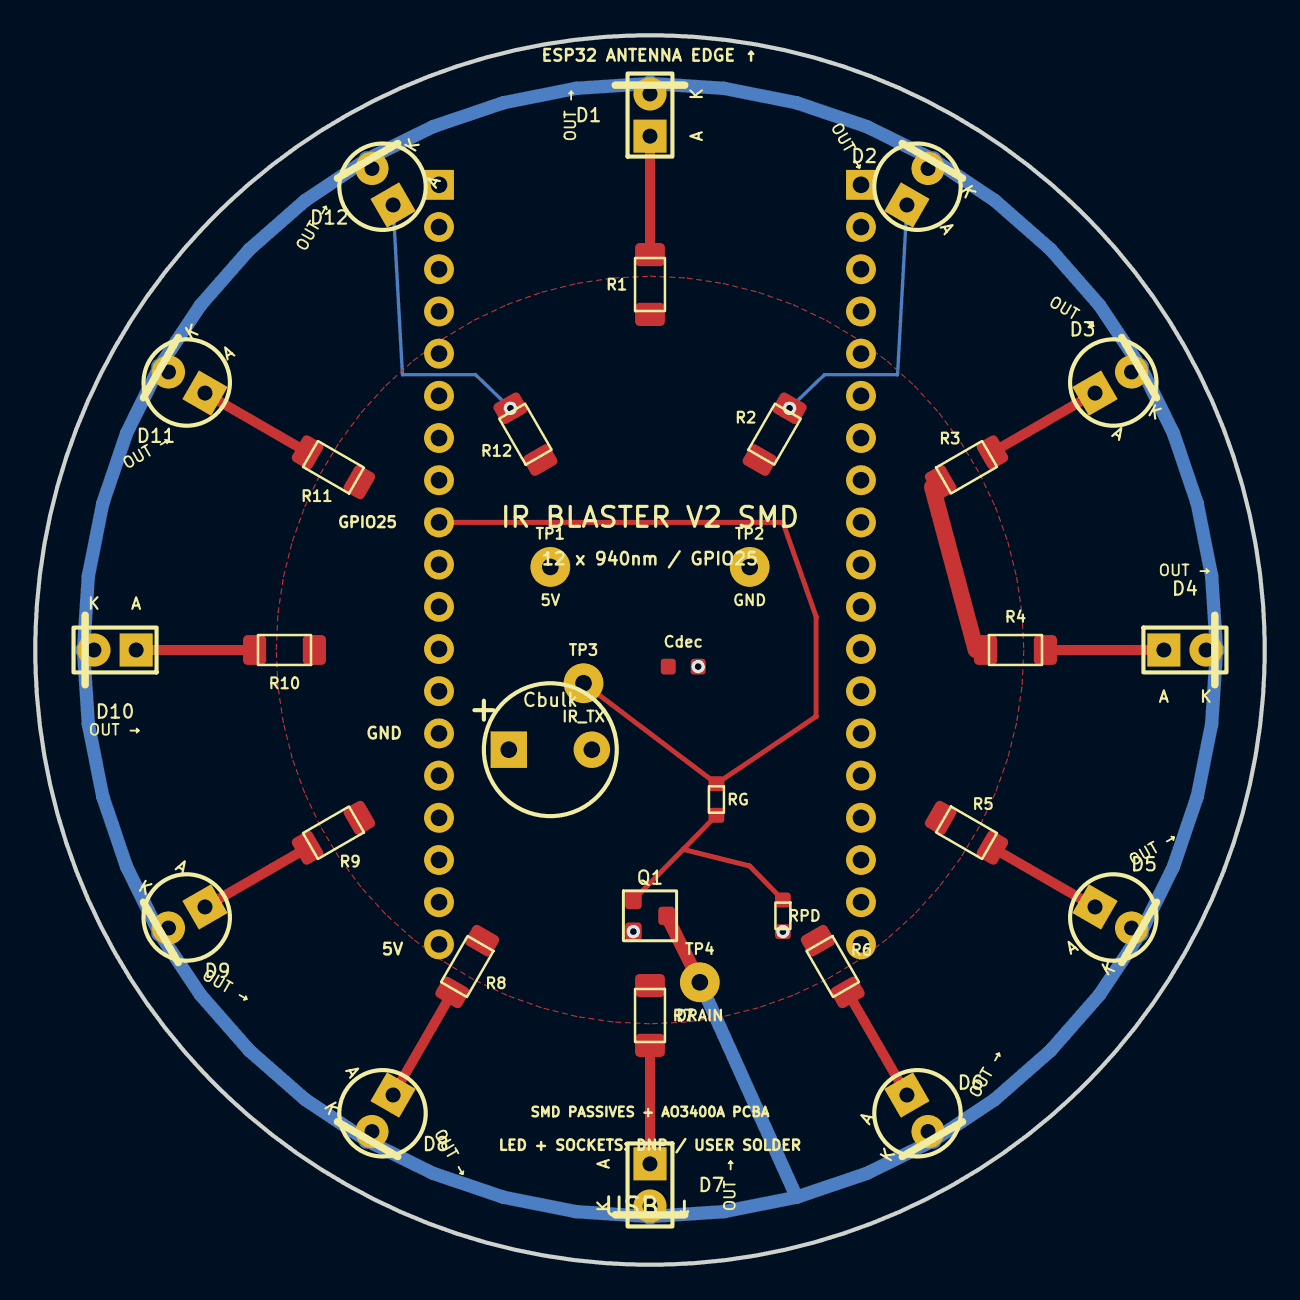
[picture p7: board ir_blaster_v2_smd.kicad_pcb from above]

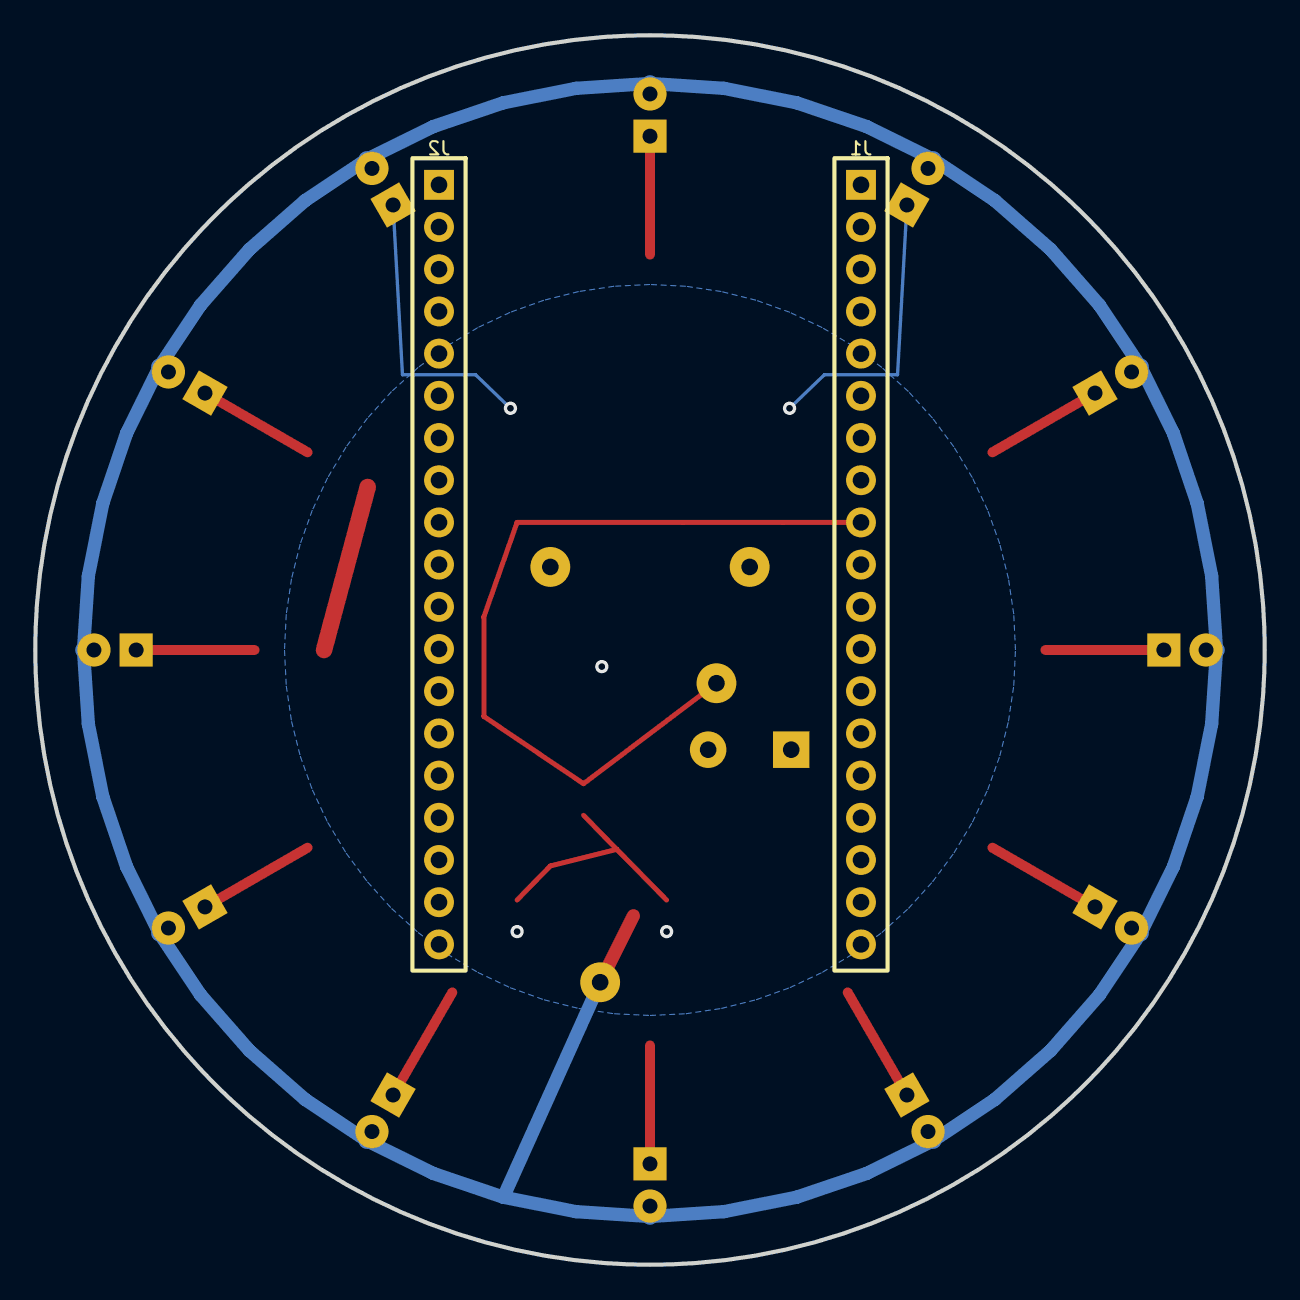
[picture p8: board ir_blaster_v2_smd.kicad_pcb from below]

Board: 2 copper layers, 74.0 x 74.0 mm, 35 parts (2 on the bottom side), 17 nets.

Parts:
Cbulk: 1000uF_10V; Cbulk_1000uF_10V
Cdec: 100nF; C_0603_1608Metric
D1, D4, D7, D10: OSI5LA7WA1B
D2, D3, D5, D6, D8, D9, D11, D12: OSI5LA5A33A-B
J1, J2: ESP32_DEVKITC_SOCKET_DNP; ESP32_DevKitC_V4_1x19
Q1: AO3400A; SOT-23
R1, R2, R3, R4, R5, R6, R7, R8, R9, R10, R11, R12: 100R 0.25W; R_1206_3216Metric
RG: 220R; R_0603_1608Metric
RPD: 10k; R_0603_1608Metric
TP1: 5V; TestPoint_D2.0mm
TP2: GND; TestPoint_D2.0mm
TP3: IR_TX; TestPoint_D2.0mm
TP4: DRAIN; TestPoint_D2.0mm

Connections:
+5V: Cbulk.1, Cdec.1, J1.19, R1.1, R2.1, R3.1, R4.1, R5.1, R6.1, R7.1, R8.1, R9.1, R10.1, R11.1, R12.1, TP1.1
D1_A: D1.1, R1.2
D2_A: D2.1, R2.2
D3_A: D3.1, R3.2
D4_A: D4.1, R4.2
D5_A: D5.1, R5.2
D6_A: D6.1, R6.2
D7_A: D7.1, R7.2
D8_A: D8.1, R8.2
D9_A: D9.1, R9.2
D10_A: D10.1, R10.2
D11_A: D11.1, R11.2
D12_A: D12.1, R12.2
GATE: Q1.1, RG.2, RPD.1
GND: Cbulk.2, Cdec.2, J1.14, Q1.2, RPD.2, TP2.1
IR_TX: J1.9, RG.1, TP3.1
LED_DRAIN: D1.2, D2.2, D3.2, D4.2, D5.2, D6.2, D7.2, D8.2, D9.2, D10.2, D11.2, D12.2, Q1.3, TP4.1

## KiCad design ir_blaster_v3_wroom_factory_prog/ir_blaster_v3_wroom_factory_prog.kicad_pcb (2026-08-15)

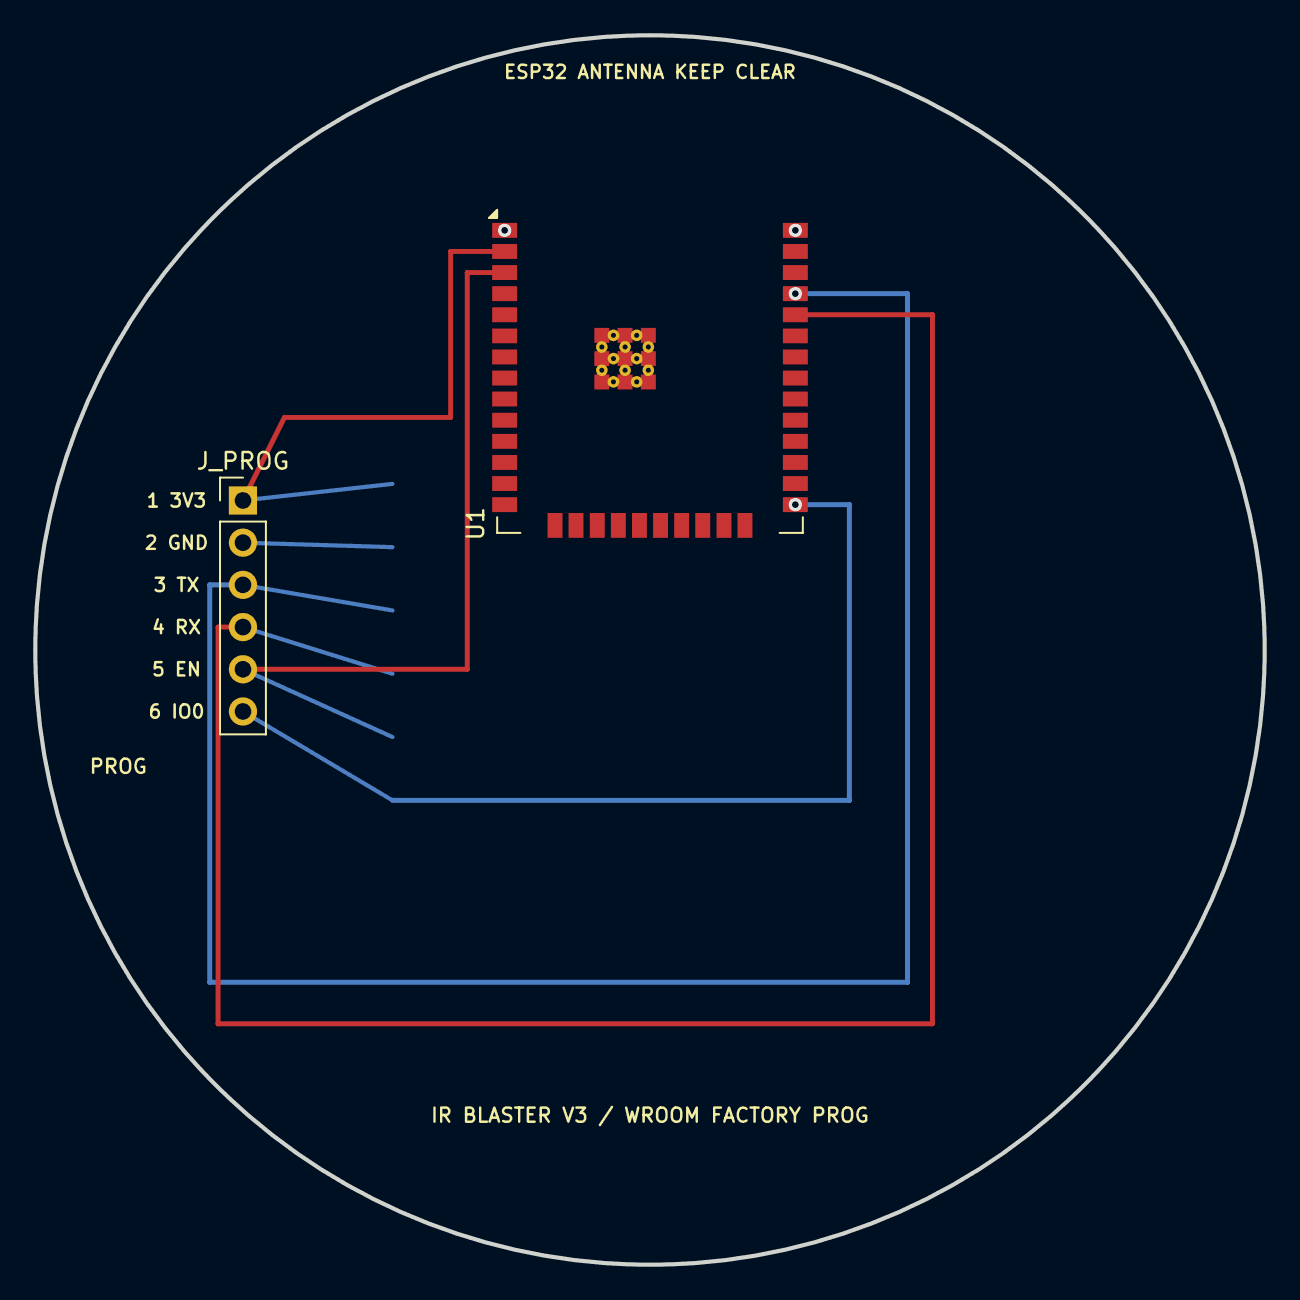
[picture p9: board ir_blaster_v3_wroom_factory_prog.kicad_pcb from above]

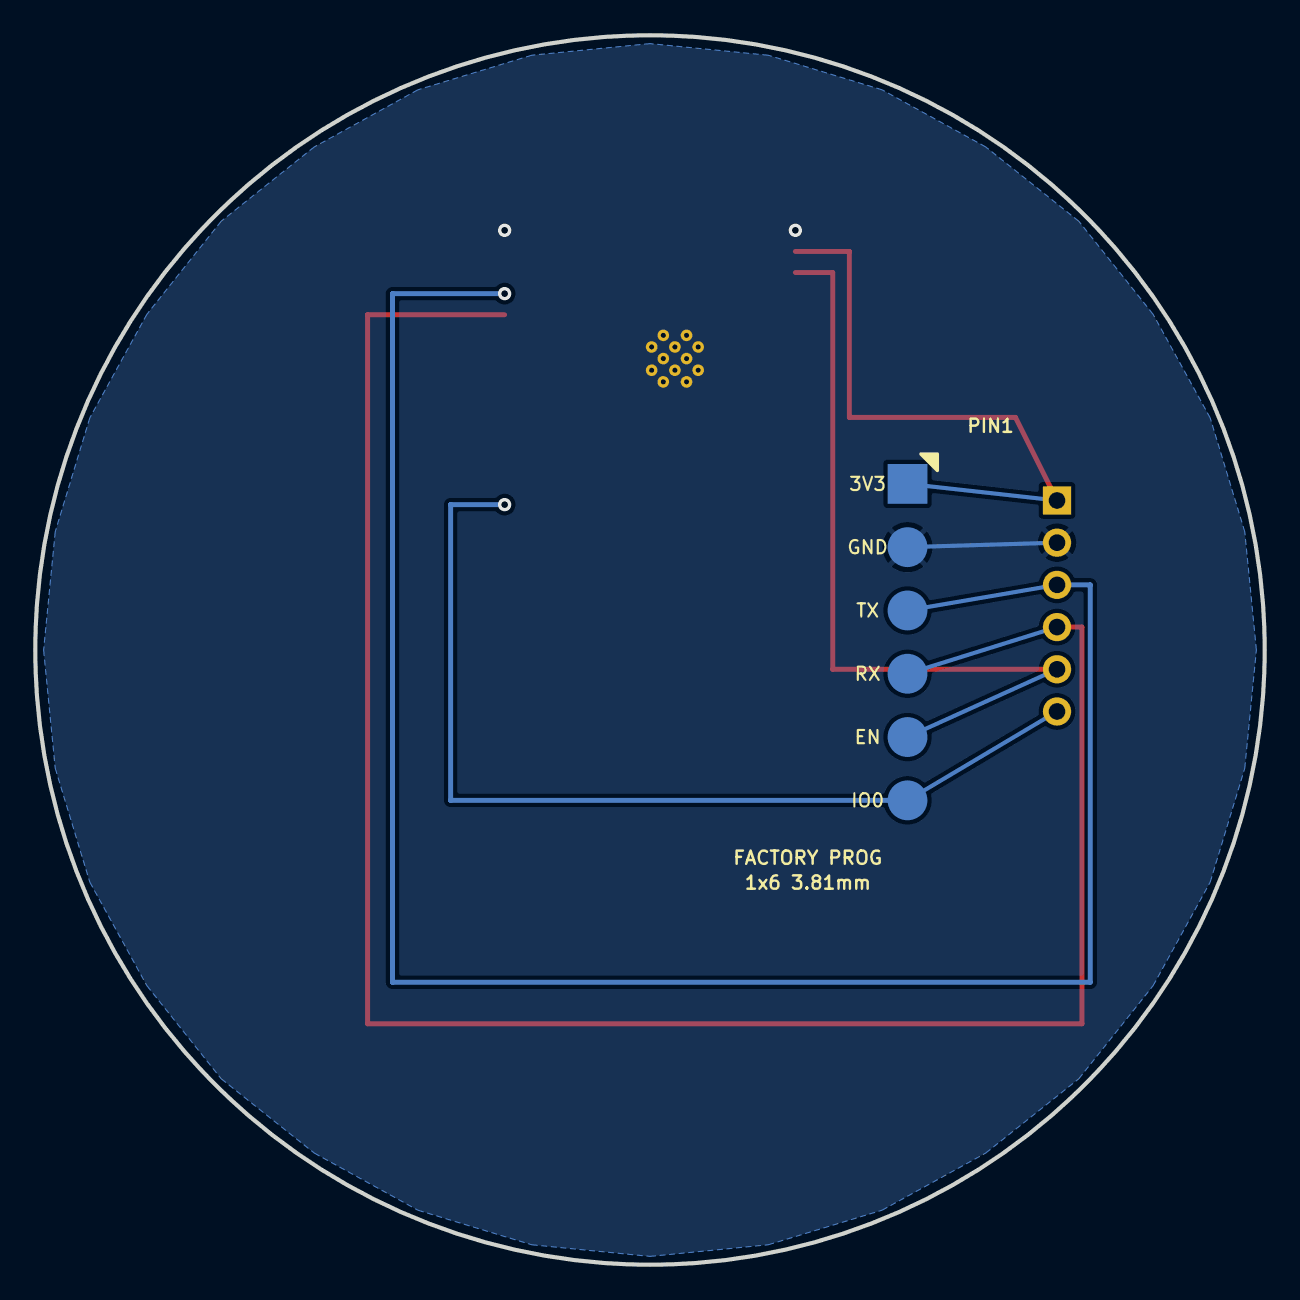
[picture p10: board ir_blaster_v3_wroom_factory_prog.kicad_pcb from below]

Board: 2 copper layers, 74.0 x 74.0 mm, 8 parts (6 on the bottom side), 6 nets.

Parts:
J_PROG: PinHeader_1x06_P2.54mm_Vertical_DNP; PinHeader_1x06_P2.54mm_Vertical
TP_PROG_3V3: 3V3; PogoPad_D2.4mm
TP_PROG_EN: EN; PogoPad_D2.4mm
TP_PROG_GND: GND; PogoPad_D2.4mm
TP_PROG_IO0: IO0; PogoPad_D2.4mm
TP_PROG_RX: RX; PogoPad_D2.4mm
TP_PROG_TX: TX; PogoPad_D2.4mm
U1: ESP32-WROOM-32E-N16; ESP32-WROOM-32E

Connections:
+3V3: J_PROG.1, TP_PROG_3V3.1, U1.2
EN: J_PROG.5, TP_PROG_EN.1, U1.3
GND: J_PROG.2, TP_PROG_GND.1, U1.1, U1.38, U1.39
IO0: J_PROG.6, TP_PROG_IO0.1, U1.25
U0RXD: J_PROG.4, TP_PROG_RX.1, U1.34
U0TXD: J_PROG.3, TP_PROG_TX.1, U1.35

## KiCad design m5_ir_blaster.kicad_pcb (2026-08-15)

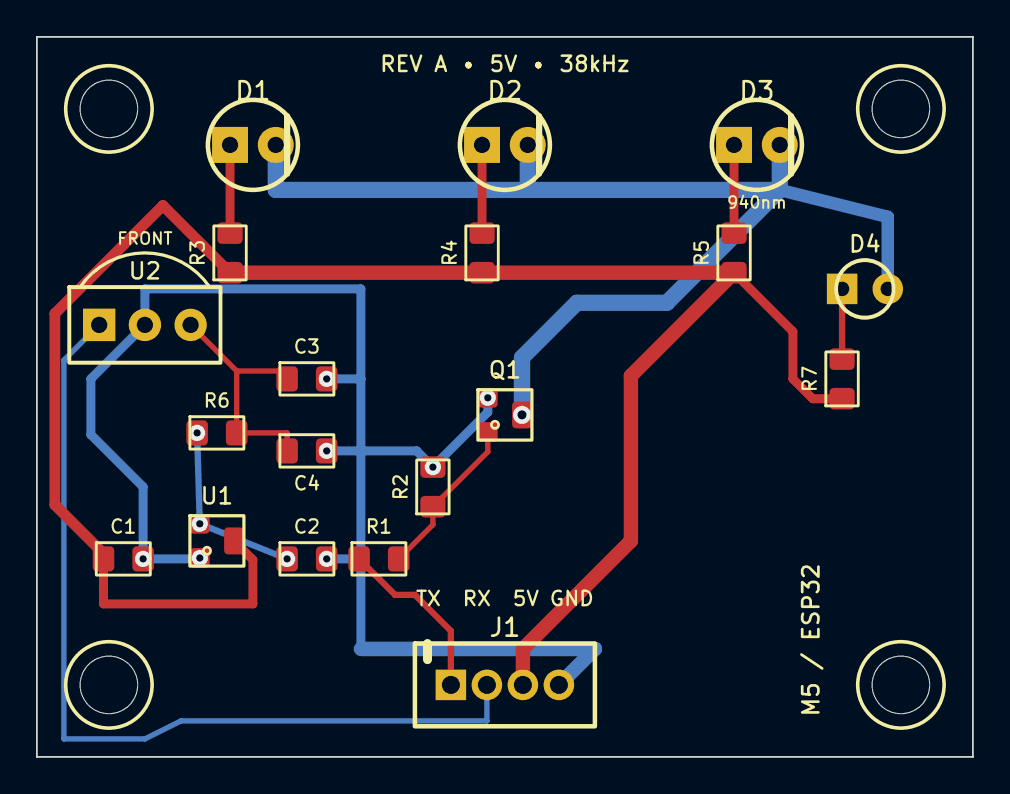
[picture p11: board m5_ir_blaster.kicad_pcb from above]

Board: 2 copper layers, 52.0 x 40.0 mm, 23 parts (0 on the bottom side), 12 nets.

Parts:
C1, C2: 1uF; C_0805
C3: 4.7uF; C_0805
C4: 100nF; C_0805
D1, D2, D3: IR_LED_940nm; LED_D5.0mm_IR
D4: TX_VISIBLE; LED_D3.0mm
H1, H2, H3, H4: M3; MountingHole_3.2mm_M3
J1: GROVE_M5_PORT; JST_PH_1x04_P2.00mm_Vertical
Q1: AO3400A; SOT-23
R1, R6: 100R; R_0805
R2: 100k; R_0805
R3, R4, R5: 33R; R_0805
R7: 1k; R_0805
U1: MCP1700-3302; SOT-23
U2: TSOP38238; TSOP_3pin_P2.54

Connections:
+3V3: C2.1, R6.1, U1.2
+5V: C1.1, J1.3, R3.1, R4.1, R5.1, R7.1, U1.3
GATE: Q1.1, R1.2, R2.1
GND: C1.2, C2.2, C3.2, C4.2, J1.4, Q1.2, R2.2, U1.1, U2.2
IR_RX: J1.2, U2.1
IR_SINK: D1.2, D2.2, D3.2, D4.2, Q1.3
IR_TX: J1.1, R1.1
LED1_A: D1.1, R3.2
LED2_A: D2.1, R4.2
LED3_A: D3.1, R5.2
RX_VCC: C3.1, C4.1, R6.2, U2.3
STATUS_A: D4.1, R7.2

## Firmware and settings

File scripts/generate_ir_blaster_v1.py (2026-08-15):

#!/usr/bin/env python3
"""Generate the IR Blaster V1 KiCad board and supporting source artifacts."""

from __future__ import annotations

import csv
import json
import math
import shutil
import sys
import uuid
from pathlib import Path


ROOT = Path(__file__).resolve().parents[1]
SMD = "--smd" in sys.argv
PROJECT = "ir_blaster_v2_smd" if SMD else "ir_blaster_v1"
OUT = ROOT / PROJECT
BOARD = OUT / f"{PROJECT}.kicad_pcb"
CX = CY = 100.0
R_BOARD = 37.0
BOARD_DIAMETER_MM = 74.0


def uid() -> str:
    return str(uuid.uuid4())


def xy_at(radius: float, deg: float) -> tuple[float, float]:
    a = math.radians(deg - 90.0)
    return CX + radius * math.cos(a), CY + radius * math.sin(a)


def fmt(v: float) -> str:
    return f"{v:.3f}".rstrip("0").rstrip(".")


def at(x: float, y: float, deg: float | None = None) -> str:
    return f"(at {fmt(x)} {fmt(y)}" + (f" {fmt(deg)}" if deg is not None else "") + ")"


def fp_text(kind: str, text: str, x: float, y: float, size: float = 0.8, layer: str = "F.SilkS", hide: bool = False) -> str:
    hidden = " hide" if hide else ""
    return f'''    (property "{kind}" "{text}" {at(x, y)} (layer "{layer}"){hidden}
      (effects (font (size {size} {size}) (thickness 0.13)))
    )'''


def led_fp(ref: str, value: str, x: float, y: float, rot: float, anet: int, wide: bool) -> str:
    body = "rect" if wide else "circle"
    shape = ('(fp_rect (start -2.5 -1.35) (end 2.5 1.35)\n'
             '      (stroke (width 0.25) (type default)) (fill none) (layer "F.SilkS"))') if wide else (
             '(fp_circle (center 0 0) (end 2.6 0)\n'
             '      (stroke (width 0.25) (type default)) (fill none) (layer "F.SilkS"))')
    return f'''  (footprint "IR_Blaster:{'OSI5LA7WA1B' if wide else 'OSI5LA5A33A-B'}" (layer "F.Cu")
    {at(x, y, rot)}
{fp_text('Reference', ref, 0, -3.7)}
{fp_text('Value', value, 0, 3.7, layer='F.Fab', hide=True)}
    {shape}
    (fp_line (start 1.8 -2.1) (end 1.8 2.1) (stroke (width 0.45) (type default)) (layer "F.SilkS"))
    (fp_text user "A" (at -1.27 2.8 {fmt(-rot)}) (layer "F.SilkS") (effects (font (size 0.7 0.7) (thickness 0.13))))
    (fp_text user "K" (at 1.27 2.8 {fmt(-rot)}) (layer "F.SilkS") (effects (font (size 0.7 0.7) (thickness 0.13))))
    (fp_text user "OUT →" (at 0 -4.8 {fmt(-rot)}) (layer "F.SilkS") (effects (font (size 0.65 0.65) (thickness 0.11))))
    (attr through_hole exclude_from_pos_files exclude_from_bom)
    (pad "1" thru_hole rect (at -1.27 0 {fmt(rot)}) (size 2 2) (drill 0.9) (layers "*.Cu" "*.Mask") (net {anet} "{ref}_A"))
    (pad "2" thru_hole circle (at 1.27 0 {fmt(rot)}) (size 2 2) (drill 0.9) (layers "*.Cu" "*.Mask") (net 3 "LED_DRAIN"))
    (model "${{KICAD9_3DMODEL_DIR}}/LED_THT.3dshapes/LED_D5.0mm_IRGrey.wrl" (offset (xyz 0 0 0)) (scale (xyz 1 1 1)) (rotate (xyz 0 0 0)))
  )'''


def resistor_fp(ref: str, value: str, x: float, y: float, rot: float, net1: int, name1: str, net2: int, name2: str, dnp: bool = False) -> str:
    if SMD:
        power = ref.startswith("R") and ref[1:].isdigit()
        half = 1.8 if power else 0.95
        pad_x = 1.4 if power else 0.9
        pad_y = 1.8 if power else 0.95
        body_x = 1.6 if power else 0.8
        body_y = 0.9 if power else 0.45
        package = "R_1206_3216Metric" if power else "R_0603_1608Metric"
        return f'''  (footprint "Resistor_SMD:{package}" (layer "F.Cu")
    {at(x, y, rot)}
{fp_text('Reference', ref, 0, -2.0 if power else -1.3, 0.65)}
{fp_text('Value', value, 0, 2.0, layer='F.Fab', hide=True)}
    (fp_rect (start -{body_x} -{body_y}) (end {body_x} {body_y}) (stroke (width 0.15) (type default)) (fill none) (layer "F.SilkS"))
    (attr smd)
    (pad "1" smd roundrect (at -{half} 0 {fmt(rot)}) (size {pad_x} {pad_y}) (layers "F.Cu" "F.Paste" "F.Mask") (roundrect_rratio 0.2) (net {net1} "{name1}"))
    (pad "2" smd roundrect (at {half} 0 {fmt(rot)}) (size {pad_x} {pad_y}) (layers "F.Cu" "F.Paste" "F.Mask") (roundrect_rratio 0.2) (net {net2} "{name2}"))
  )'''
    attrs = " through_hole" + (" exclude_from_pos_files exclude_from_bom" if dnp else "")
    return f'''  (footprint "IR_Blaster:R_Axial_DIN0207_P10.16mm" (layer "F.Cu")
    {at(x, y, rot)}
{fp_text('Reference', ref, 0, -2.0)}
{fp_text('Value', value, 0, 2.0, layer='F.Fab', hide=True)}
    (fp_rect (start -3.5 -1.25) (end 3.5 1.25) (stroke (width 0.22) (type default)) (fill none) (layer "F.SilkS"))
    (fp_line (start -5.08 0) (end -3.5 0) (stroke (width 0.2) (type default)) (layer "F.SilkS"))
    (fp_line (start 3.5 0) (end 5.08 0) (stroke (width 0.2) (type default)) (layer "F.SilkS"))
    (attr{attrs})
    (pad "1" thru_hole circle (at -5.08 0 {fmt(rot)}) (size 2 2) (drill 0.9) (layers "*.Cu" "*.Mask") (zone_connect 2) (net {net1} "{name1}"))
    (pad "2" thru_hole circle (at 5.08 0 {fmt(rot)}) (size 2 2) (drill 0.9) (layers "*.Cu" "*.Mask") (zone_connect 2) (net {net2} "{name2}"))
    (model "${{KICAD9_3DMODEL_DIR}}/Resistor_THT.3dshapes/R_Axial_DIN0207_L6.3mm_D2.5mm_P10.16mm_Horizontal.wrl" (offset (xyz 0 0 0)) (scale (xyz 1 1 1)) (rotate (xyz 0 0 0)))
  )'''


def simple_2pin_fp(ref: str, value: str, x: float, y: float, pitch: float, net1: tuple[int, str], net2: tuple[int, str], polarized: bool = False) -> str:
    marker = '(fp_text user "+" (at -4 -2.5) (layer "F.SilkS") (effects (font (size 1.5 1.5) (thickness 0.25))))' if polarized else ""
    return f'''  (footprint "IR_Blaster:{ref}_{value}" (layer "F.Cu")
    {at(x, y)}
{fp_text('Reference', ref, 0, -3.0)}
{fp_text('Value', value, 0, 3.0, layer='F.Fab', hide=True)}
    (fp_circle (center 0 0) (end 4 0) (stroke (width 0.25) (type default)) (fill none) (layer "F.SilkS"))
    {marker}
    (attr through_hole)
    (pad "1" thru_hole rect (at {fmt(-pitch/2)} 0) (size 2.2 2.2) (drill 1.0) (layers "*.Cu" "*.Mask") (net {net1[0]} "{net1[1]}"))
    (pad "2" thru_hole circle (at {fmt(pitch/2)} 0) (size 2.2 2.2) (drill 1.0) (layers "*.Cu" "*.Mask") (net {net2[0]} "{net2[1]}"))
  )'''


def header_fp(ref: str, x: float, y0: float, left: bool) -> str:
    pin_names_left = ["3V3", "EN", "VP", "VN", "IO34", "IO35", "IO32", "IO33", "GPIO25", "IO26", "IO27", "IO14", "IO12", "GND", "IO13", "D2", "D3", "CMD", "5V"]
    pin_names_right = ["GND", "IO23", "IO22", "TX", "RX", "IO21", "GND", "IO19", "IO18", "IO5", "IO17", "IO16", "IO4", "IO0", "IO2", "IO15", "D1", "D0", "CLK"]
    names = pin_names_left if left else pin_names_right
    pads = []
    for i, name in enumerate(names, 1):
        net = None
        if left and name == "GPIO25": net = (4, "IR_TX")
        elif left and name == "5V": net = (1, "+5V")
        elif left and name == "GND": net = (2, "GND")
        net_s = f' (net {net[0]} "{net[1]}")' if net else ""
        shape = "rect" if i == 1 else "circle"
        pads.append(f'    (pad "{i}" thru_hole {shape} (at 0 {fmt((i-1)*2.54)}) (size 1.8 1.8) (drill 1.0) (layers "*.Cu" "*.Mask"){net_s})')
    return f'''  (footprint "IR_Blaster:ESP32_DevKitC_V4_1x19" (layer "B.Cu")
    {at(x, y0)}
{fp_text('Reference', ref, 0, -2.2, layer='B.SilkS')}
{fp_text('Value', 'ESP32_DEVKITC_SOCKET_DNP', 0, 48.0, layer='B.Fab', hide=True)}
    (fp_rect (start -1.6 -1.6) (end 1.6 47.3) (stroke (width 0.25) (type default)) (fill none) (layer "B.SilkS"))
    (attr through_hole exclude_from_pos_files exclude_from_bom)
{chr(10).join(pads)}
    (model "${{KICAD9_3DMODEL_DIR}}/Connector_PinSocket_2.54mm.3dshapes/PinSocket_1x19_P2.54mm_Vertical.wrl" (offset (xyz 0 0 0)) (scale (xyz 1 1 1)) (rotate (xyz 0 180 0)))
  )'''


def q_fp() -> str:
    if SMD:
        return f'''  (footprint "Package_TO_SOT_SMD:SOT-23" (layer "F.Cu")
    {at(100, 116)}
{fp_text('Reference', 'Q1', 0, -2.3)}
{fp_text('Value', 'AO3400A', 0, 2.3, layer='F.Fab', hide=True)}
    (fp_rect (start -1.6 -1.5) (end 1.6 1.5) (stroke (width 0.18) (type default)) (fill none) (layer "F.SilkS"))
    (attr smd)
    (pad "1" smd roundrect (at -1 -0.95) (size 1 1.1) (layers "F.Cu" "F.Paste" "F.Mask") (roundrect_rratio 0.2) (net 5 "GATE"))
    (pad "2" smd roundrect (at -1 0.95) (size 1 1.1) (layers "F.Cu" "F.Paste" "F.Mask") (roundrect_rratio 0.2) (net 2 "GND"))
    (pad "3" smd roundrect (at 1 0) (size 1 1.1) (layers "F.Cu" "F.Paste" "F.Mask") (roundrect_rratio 0.2) (net 3 "LED_DRAIN"))
  )'''
    return f'''  (footprint "IR_Blaster:INK021ABS1_TO92S" (layer "F.Cu")
    {at(100, 116)}
{fp_text('Reference', 'Q1', 0, -3.2)}
{fp_text('Value', 'INK021ABS1-T112', 0, 3.2, layer='F.Fab', hide=True)}
    (fp_rect (start -4 -2.0) (end 4 2.0) (stroke (width 0.3) (type default)) (fill none) (layer "F.SilkS"))
    (fp_text user "S   D   G" (at 0 3.0) (layer "F.SilkS") (effects (font (size 0.8 0.8) (thickness 0.14))))
    (attr through_hole)
    (pad "1" thru_hole rect (at -2.5 0) (size 2 2) (drill 0.9) (layers "*.Cu" "*.Mask") (net 2 "GND"))
    (pad "2" thru_hole circle (at 0 0) (size 2 2) (drill 0.9) (layers "*.Cu" "*.Mask") (net 3 "LED_DRAIN"))
    (pad "3" thru_hole circle (at 2.5 0) (size 2 2) (drill 0.9) (layers "*.Cu" "*.Mask") (net 5 "GATE"))
    (model "${{KICAD9_3DMODEL_DIR}}/Package_TO_SOT_THT.3dshapes/TO-92_Inline.wrl" (offset (xyz 0 0 0)) (scale (xyz 1 1 1)) (rotate (xyz 0 0 0)))
  )'''


def tp_fp(ref: str, label: str, x: float, y: float, net: tuple[int, str]) -> str:
    return f'''  (footprint "IR_Blaster:TestPoint_D2.0mm" (layer "F.Cu")
    {at(x, y)}
{fp_text('Reference', ref, 0, -2.0, 0.65)}
{fp_text('Value', label, 0, 2.0, 0.65, 'F.SilkS')}
    (attr through_hole exclude_from_bom exclude_from_pos_files)
    (pad "1" thru_hole circle (at 0 0) (size 2.4 2.4) (drill 1.0) (layers "*.Cu" "*.Mask") (net {net[0]} "{net[1]}"))
  )'''


def cdec_fp() -> str:
    if not SMD:
        return simple_2pin_fp("Cdec", "100nF", 102, 101, 2.54, (1, "+5V"), (2, "GND"))
    return f'''  (footprint "Capacitor_SMD:C_0603_1608Metric" (layer "F.Cu")
    {at(102, 101)}
{fp_text('Reference', 'Cdec', 0, -1.5, 0.65)}
{fp_text('Value', '100nF', 0, 1.5, layer='F.Fab', hide=True)}
    (attr smd)
    (pad "1" smd roundrect (at -0.9 0) (size 0.9 0.95) (layers "F.Cu" "F.Paste" "F.Mask") (roundrect_rratio 0.2) (net 1 "+5V"))
    (pad "2" smd roundrect (at 0.9 0) (size 0.9 0.95) (layers "F.Cu" "F.Paste" "F.Mask") (roundrect_rratio 0.2) (net 2 "GND"))
  )'''


def segment(a: tuple[float, float], b: tuple[float, float], width: float, layer: str, net: int) -> str:
    return f'  (segment (start {fmt(a[0])} {fmt(a[1])}) (end {fmt(b[0])} {fmt(b[1])}) (width {fmt(width)}) (layer "{layer}") (net {net}))'


def via(x: float, y: float, net: int) -> str:
    return f'  (via (at {fmt(x)} {fmt(y)}) (size 0.8) (drill 0.4) (layers "F.Cu" "B.Cu") (net {net}))'


def ring(radius: float, width: float, net: int, layer: str, steps: int = 48) -> list[str]:
    pts = [xy_at(radius, i * 360 / steps) for i in range(steps)]
    return [segment(pts[i], pts[(i + 1) % steps], width, layer, net) for i in range(steps)]


def circle_zone(radius: float, net: int, name: str, layer: str, steps: int = 64) -> str:
    pts = " ".join(f"(xy {fmt(x)} {fmt(y)})" for x, y in [xy_at(radius, i * 360 / steps) for i in range(steps)])
    return f'''  (zone (net {net}) (net_name "{name}") (layer "{layer}") (hatch edge 0.5)
    (connect_pads (clearance 0.25))
    (min_thickness 0.25)
    (fill yes (thermal_gap 0.3) (thermal_bridge_width 0.3))
    (polygon (pts {pts}))
  )'''


def board_text(text: str, x: float, y: float, size: float = 1.0, justify: str = "") -> str:
    just = f" (justify {justify})" if justify else ""
    return f'''  (gr_text "{text}" {at(x, y)} (layer "F.SilkS")
    (effects (font (size {size} {size}) (thickness {fmt(max(0.15, size*0.16))})){just})
  )'''


def generate_board() -> None:
    nets = ['  (net 0 "")', '  (net 1 "+5V")', '  (net 2 "GND")', '  (net 3 "LED_DRAIN")', '  (net 4 "IR_TX")', '  (net 5 "GATE")']
    for i in range(1, 13):
        nets.append(f'  (net {5+i} "D{i}_A")')

    fps: list[str] = []
    led_points = []
    res_points = []
    for i, deg in enumerate(range(0, 360, 30), 1):
        wide = deg % 90 == 0
        lx, ly = xy_at(32.2, deg)
        resistor_radius = (15.0 if SMD and deg in (30, 330) else 22.0) if SMD else 24.7
        rx, ry = xy_at(resistor_radius, deg)
        # KiCad footprint local +X points outward when rotated by (radial angle - 90°).
        footprint_rot = 90 - deg
        fps.append(led_fp(f"D{i}", "OSI5LA7WA1B" if wide else "OSI5LA5A33A-B", lx, ly, footprint_rot, 5+i, wide))
        fps.append(resistor_fp(f"R{i}", "100R 0.25W", rx, ry, footprint_rot, 1, "+5V", 5+i, f"D{i}_A"))
        led_points.append((deg, lx, ly))
        res_points.append((deg, rx, ry))

    fps += [
        header_fp("J1", 87.3, 72.0, True),
        header_fp("J2", 112.7, 72.0, False),
        q_fp(),
        resistor_fp("RG", "220R", 104, 109, -90, 4, "IR_TX", 5, "GATE"),
        resistor_fp("RPD", "10k", 108, 116, -90, 5, "GATE", 2, "GND"),
        simple_2pin_fp("Cbulk", "1000uF_10V", 94, 106, 5.0, (1, "+5V"), (2, "GND"), True),
        cdec_fp(),
        tp_fp("TP1", "5V", 94, 95, (1, "+5V")),
        tp_fp("TP2", "GND", 106, 95, (2, "GND")),
        tp_fp("TP3", "IR_TX", 96, 102, (4, "IR_TX")),
        tp_fp("TP4", "DRAIN", 103, 120, (3, "LED_DRAIN")),
    ]

    tracks: list[str] = []
    tracks += ring(34.1, 0.8, 3, "B.Cu")
    for i, (deg, lx, ly) in enumerate(led_points, 1):
        ux, uy = math.cos(math.radians(deg - 90)), math.sin(math.radians(deg - 90))
        resistor_radius = (15.0 if SMD and deg in (30, 330) else 22.0) if SMD else 24.7
        resistor_half = 1.8 if SMD else 5.08
        res_in = xy_at(resistor_radius - resistor_half, deg)
        res_out = xy_at(resistor_radius + resistor_half, deg)
        led_an = (lx - 1.27 * ux, ly - 1.27 * uy)
        led_k = (lx + 1.27 * ux, ly + 1.27 * uy)
        ringd = xy_at(34.1, deg)
        if SMD and deg in (30, 330):
            through_y = 83.43
            outside_x = 114.9 if deg == 30 else 85.1
            inner_x = 110.5 if deg == 30 else 89.5
            tracks += [
                via(res_out[0], res_out[1], 5+i),
                segment(res_out, (inner_x, through_y), 0.2, "B.Cu", 5+i),
                segment((inner_x, through_y), (outside_x, through_y), 0.2, "B.Cu", 5+i),
                segment((outside_x, through_y), led_an, 0.2, "B.Cu", 5+i),
            ]
        else:
            tracks.append(segment(res_out, led_an, 0.6, "F.Cu", 5+i))
        tracks.append(segment(led_k, ringd, 1.0, "B.Cu", 3))

    # Header and central component connections.
    j1_gpio25 = (87.3, 72.0 + 8*2.54)
    tracks += [
        segment(j1_gpio25, (92, 92.32), 0.3, "F.Cu", 4),
        segment((92, 92.32), (98, 92.32), 0.3, "F.Cu", 4),
        segment((98, 92.32), (108, 92.32), 0.3, "F.Cu", 4),
        segment((108, 92.32), (110, 98), 0.3, "F.Cu", 4),
        segment((110, 98), (110, 104), 0.3, "F.Cu", 4),
        segment((116.9916, 90.19), (119.62, 100), 1.0, "F.Cu", 1),
    ]
    if SMD:
        tracks += [
            segment((101, 116), (103, 120), 0.8, "F.Cu", 3),
            segment((103, 120), xy_at(34.1, 165), 0.8, "B.Cu", 3),
            segment((110, 104), (104, 108.05), 0.3, "F.Cu", 4),
            segment((104, 109.95), (102, 112), 0.3, "F.Cu", 5),
            segment((102, 112), (99, 115.05), 0.3, "F.Cu", 5),
            segment((108, 115.05), (106, 113), 0.3, "F.Cu", 5),
            segment((106, 113), (102, 112), 0.3, "F.Cu", 5),
            segment((96, 102), (104, 108.05), 0.3, "F.Cu", 4),
            via(99, 116.95, 2),
            via(108, 116.95, 2),
            via(102.9, 101, 2),
        ]
    else:
        tracks += [
            segment((100, 116), (103, 120), 0.8, "B.Cu", 3),
            segment((103, 120), xy_at(34.1, 165), 0.8, "B.Cu", 3),
            segment((110, 104), (104, 103.92), 0.3, "F.Cu", 4),
            segment((104, 114.08), (102.5, 116), 0.3, "F.Cu", 5),
            segment((108, 110.92), (102.5, 116), 0.3, "F.Cu", 5),
            segment((96, 102), (104, 103.92), 0.3, "F.Cu", 4),
        ]

    silks = [
        board_text("IR BLASTER V2 SMD" if SMD else "IR BLASTER V1", 100, 92, 1.2),
        board_text("12 x 940nm / GPIO25", 100, 94.5, 0.75),
        board_text("USB ↓", 100, 133.5, 1.1),
        board_text("ESP32 ANTENNA EDGE ↑", 100, 64.2, 0.7),
        board_text("LED + SOCKETS: DNP / USER SOLDER", 100, 129.8, 0.62),
        board_text("SMD PASSIVES + AO3400A PCBA" if SMD else "THT DRIVER COMPONENTS", 100, 127.8, 0.58),
        board_text("5V", 84.5, 118.0, 0.7),
        board_text("GND", 84.0, 105.0, 0.7),
        board_text("GPIO25", 83.0, 92.3, 0.65),
    ]

    pcb = f'''(kicad_pcb (version 20240108) (generator pcbnew)
  (general (thickness 1.6))
  (paper "A4")
  (layers
    (0 "F.Cu" signal)
    (31 "B.Cu" signal)
    (36 "B.SilkS" user "b.silkscreen")
    (37 "F.SilkS" user "f.silkscreen")
    (38 "B.Mask" user)
    (39 "F.Mask" user)
    (44 "Edge.Cuts" user)
  )
  (setup (pad_to_mask_clearance 0) (allow_soldermask_bridges_in_footprints no))
{chr(10).join(nets)}
{chr(10).join(fps)}
{chr(10).join(silks)}
  (gr_circle (center {CX} {CY}) (end {CX+R_BOARD} {CY}) (stroke (width 0.25) (type default)) (fill none) (layer "Edge.Cuts"))
  (gr_rect (start 86.03 70.71) (end 113.97 119.0) (stroke (width 0.15) (type dash)) (fill none) (layer "Dwgs.User"))
{chr(10).join(tracks)}
{circle_zone(22.5, 1, '+5V', 'F.Cu')}
{circle_zone(22.0, 2, 'GND', 'B.Cu')}
)\n'''
    BOARD.write_text(pcb)


def generate_schematic() -> None:
    # Valid KiCad schematic overview. PCB connectivity is authoritative and fully DRC checked.
    def text(t, x, y, s=1.27):
        esc = t.replace('"', '\\"')
        return f'''  (text "{esc}" (exclude_from_sim no) (at {x} {y} 0) (effects (font (size {s} {s})) (justify left bottom)) (uuid "{uid()}"))'''
    items = [text(("IR BLASTER V2 SMD" if SMD else "IR BLASTER V1") + " — GPIO25 low-side switched 12-channel IR emitter", 20, 18, 1.6)]
    items += [text("ELECTRICAL NETLIST (PCB is authoritative)", 20, 28, 1.2)]
    for i in range(12):
        y = 38 + i * 7.5
        items += [text(f"+5V -> R{i+1} 100R -> D{i+1} anode; D{i+1} cathode -> LED_DRAIN", 25, y, 0.9)]
    items += [text("LED_DRAIN -> Q1 pin 2 DRAIN; Q1 pin 1 SOURCE -> GND", 25, 132, 0.95)]
    items += [text("GPIO25 / IR_TX -> RG 220R -> Q1 pin 3 GATE", 25, 140, 0.95)]
    items += [text("RPD 10k: GATE -> GND", 25, 148, 0.95), text("Cbulk 1000uF + Cdec 100nF: +5V -> GND", 25, 156, 0.95)]
    items += [text("D1,D4,D7,D10 = OSI5LA7WA1B wide 100°; remaining LEDs = OSI5LA5A33A-B narrow 30°", 25, 166, 0.85)]
    items += [text("Confirmed mapping: both LED types pin 1=A, pin 2=K; Q1 pin 1=S, pin 2=D, pin 3=G", 25, 174, 0.85)]
    sch = f'''(kicad_sch
  (version 20250114)
  (generator "eeschema")
  (generator_version "9.0")
  (uuid "{uid()}")
  (paper "A4")
  (lib_symbols)
{chr(10).join(items)}
  (sheet_instances (path "/" (page "1")))
  (embedded_fonts no)
)\n'''
    (OUT / f"{PROJECT}.kicad_sch").write_text(sch)


def generate_project() -> None:
    pro = {
        "boards": [], "cvpcb": {}, "erc": {}, "libraries": {},
        "meta": {"filename": f"{PROJECT}.kicad_pro", "version": 1},
        "net_settings": {
            "classes": [
                {"bus_width": 12, "clearance": 0.25, "diff_pair_gap": 0.25, "diff_pair_via_gap": 0.25, "diff_pair_width": 0.2, "line_style": 0, "microvia_diameter": 0.3, "microvia_drill": 0.1, "name": "Default", "pcb_color": "rgba(0,0,0,0)", "schematic_color": "rgba(0,0,0,0)", "track_width": 0.3, "via_diameter": 0.8, "via_drill": 0.4, "wire_width": 6},
                {"bus_width": 12, "clearance": 0.25, "diff_pair_gap": 0.25, "diff_pair_via_gap": 0.25, "diff_pair_width": 0.2, "line_style": 0, "microvia_diameter": 0.3, "microvia_drill": 0.1, "name": "IR_POWER", "pcb_color": "rgba(255,128,0,1)", "schematic_color": "rgba(255,128,0,1)", "track_width": 1.0, "via_diameter": 1.0, "via_drill": 0.5, "wire_width": 6}
            ],
            "meta": {"version": 3}, "net_colors": None,
            "netclass_assignments": {"+5V": "IR_POWER", "GND": "IR_POWER", "LED_DRAIN": "IR_POWER"}, "netclass_patterns": []
        },
        "pcbnew": {}, "schematic": {}, "sheets": [], "text_variables": {"BOARD_DIAMETER_MM": "74.0"}
    }
    (OUT / f"{PROJECT}.kicad_pro").write_text(json.dumps(pro, indent=2, ensure_ascii=False) + "\n")
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

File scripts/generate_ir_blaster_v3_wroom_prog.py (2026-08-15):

#!/usr/bin/env python3
"""Generate the isolated WROOM factory-programming interface revision.

This revision intentionally lives beside V1/V2 and does not overwrite them.
It implements the WROOM module land pattern, UART0 programming nets, a DNP
1x6 prototype header, and bottom-side 2x3 pogo pads.
"""

from __future__ import annotations

import csv
import json
import re
import uuid
from pathlib import Path


ROOT = Path(__file__).resolve().parents[1]
PROJECT = "ir_blaster_v3_wroom_factory_prog"
OUT = ROOT / PROJECT
BOARD = OUT / f"{PROJECT}.kicad_pcb"
KICAD_FP = Path("/Applications/KiCad/KiCad.app/Contents/SharedSupport/footprints")
CX = CY = 100.0
RADIUS = 37.0


NETS = {
    "GND": 1,
    "+3V3": 2,
    "U0TXD": 3,
    "U0RXD": 4,
    "EN": 5,
    "IO0": 6,
}


def uid() -> str:
    return str(uuid.uuid4())


def fmt(v: float) -> str:
    return f"{v:.3f}".rstrip("0").rstrip(".")


def fp_text(kind: str, text: str, x: float, y: float, layer: str, size: float = 0.8, hide: bool = False) -> str:
    hidden = " hide" if hide else ""
    justify = ' (justify mirror)' if layer.startswith("B.") else ""
    return f'''    (property "{kind}" "{text}" (at {fmt(x)} {fmt(y)}) (layer "{layer}"){hidden}
      (effects (font (size {size} {size}) (thickness 0.13)){justify})
    )'''


def add_nets_to_pads(text: str, pad_map: dict[str, tuple[int, str]]) -> str:
    """Add board-net clauses to every matching pad block in a library footprint."""
    starts = list(re.finditer(r'\(pad\s+"([^"]+)"', text))
    for match in reversed(starts):
        pad = match.group(1)
        if pad not in pad_map:
            continue
        depth = 0
        end = None
        for i in range(match.start(), len(text)):
            if text[i] == "(":
                depth += 1
            elif text[i] == ")":
                depth -= 1
                if depth == 0:
                    end = i
                    break
        if end is None:
            raise ValueError(f"Unclosed pad {pad}")
        net_id, name = pad_map[pad]
        text = text[:end] + f'\n        (net {net_id} "{name}")' + text[end:]
    return text


def library_footprint(path: Path, ref: str, value: str, x: float, y: float,
                      pad_map: dict[str, tuple[int, str]], dnp: bool = False) -> str:
    src = path.read_text()
    first_nl = src.index("\n")
    body = src[first_nl + 1:src.rfind(")")]
    body = re.sub(r'^\s*\((version|generator|generator_version)[^\n]*\)\s*$', "", body, flags=re.M)
    body = re.sub(r'\(property "Reference" "[^"]+"', f'(property "Reference" "{ref}"', body, count=1)
    body = re.sub(r'\(property "Value" "[^"]+"', f'(property "Value" "{value}"', body, count=1)
    body = add_nets_to_pads(body, pad_map)
    if dnp:
        body = body.replace("(attr through_hole)", "(attr through_hole exclude_from_bom exclude_from_pos_files)")
    library_name = path.parent.name.removesuffix(".pretty")
    return f'''  (footprint "{library_name}:{path.stem}" (layer "F.Cu")
    (at {fmt(x)} {fmt(y)})
{body}
  )'''


def wroom_fp() -> str:
    path = KICAD_FP / "RF_Module.pretty" / "ESP32-WROOM-32E.kicad_mod"
    mapping = {
        "1": (NETS["GND"], "GND"),
        "2": (NETS["+3V3"], "+3V3"),
        "3": (NETS["EN"], "EN"),
        "25": (NETS["IO0"], "IO0"),
        "34": (NETS["U0RXD"], "U0RXD"),
        "35": (NETS["U0TXD"], "U0TXD"),
        "38": (NETS["GND"], "GND"),
        "39": (NETS["GND"], "GND"),
    }
    fp = library_footprint(path, "U1", "ESP32-WROOM-32E-N16", 100, 80, mapping)
    # KiCad's official footprint uses 0.20 mm thermal vias. Use JLCPCB's
    # standard-cost 0.30 mm finished drill while keeping the official pad grid.
    fp = fp.replace('(size 0.6 0.6)\n\t\t(drill 0.2)', '(size 0.7 0.7)\n\t\t(drill 0.3)')
    return fp


def prog_header_fp() -> str:
    path = KICAD_FP / "Connector_PinHeader_2.54mm.pretty" / "PinHeader_1x06_P2.54mm_Vertical.kicad_mod"
    names = ["+3V3", "GND", "U0TXD", "U0RXD", "EN", "IO0"]
    mapping = {str(i + 1): (NETS[name], name) for i, name in enumerate(names)}
    fp = library_footprint(path, "J_PROG", "PinHeader_1x06_P2.54mm_Vertical_DNP", 75.5, 91, mapping, True)
    fp = fp.replace('(at 75.5 91)', '(at 75.5 91)')
    return fp


def pogo_fp(ref: str, label: str, x: float, y: float, net: str, pin1: bool = False) -> str:
    shape = "rect" if pin1 else "circle"
    marker = '    (fp_poly (pts (xy -1.8 -1.8) (xy -0.8 -1.8) (xy -1.8 -0.8)) (stroke (width 0.2) (type default)) (fill yes) (layer "B.SilkS"))\n' if pin1 else ""
    return f'''  (footprint "FactoryProg:PogoPad_D2.4mm" (layer "B.Cu")
    (at {fmt(x)} {fmt(y)})
{fp_text('Reference', ref, 0, 2.2, 'B.SilkS', 0.6, True)}
{fp_text('Value', label, 2.4, 0, 'B.SilkS', 0.8)}
{marker}    (attr smd exclude_from_bom exclude_from_pos_files)
    (pad "1" smd {shape} (at 0 0) (size 2.4 2.4) (layers "B.Cu" "B.Mask") (net {NETS[net]} "{net}"))
  )'''


def via(x: float, y: float, net: str) -> str:
    return f'  (via (at {fmt(x)} {fmt(y)}) (size 0.8) (drill 0.4) (layers "F.Cu" "B.Cu") (net {NETS[net]}))'


def seg(a: tuple[float, float], b: tuple[float, float], net: str, layer: str = "F.Cu", width: float = 0.3) -> str:
    return f'  (segment (start {fmt(a[0])} {fmt(a[1])}) (end {fmt(b[0])} {fmt(b[1])}) (width {fmt(width)}) (layer "{layer}") (net {NETS[net]}))'


def board_text(text: str, x: float, y: float, layer: str = "F.SilkS", size: float = 0.8) -> str:
    return f'''  (gr_text "{text}" (at {fmt(x)} {fmt(y)}) (layer "{layer}")
    (effects (font (size {size} {size}) (thickness 0.15)){' (justify mirror)' if layer == 'B.SilkS' else ''})
  )'''
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

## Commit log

2026-08-15 Initial public KiCad and JLCPCB backup
    [BOM.csv, BOM_JLCPCB.csv, BOM_JLCPCB_SMD_ONLY.csv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]
2026-08-15 Keep generated JLCPCB CPL coordinates corrected
    [generate_ir_blaster_v3_wroom_prog.py]
